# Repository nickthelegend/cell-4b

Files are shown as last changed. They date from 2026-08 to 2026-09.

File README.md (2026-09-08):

# CELL-4B

A blood-gated, airgapped hardware wallet on a Raspberry Pi **4B** — a fork of
[z0r0z/cell](https://github.com/z0r0z/cell) rebuilt around a board you can
actually buy.

The device signs Ethereum transactions, but only after proving that a living
human is present: either a **pulse** at the touch tier, or **fresh blood** in a
cartridge. It never touches the network. Only pixels cross the airgap — a QR
code in, a QR code out.

```
92 × 128 × 42 mm   ·   12 printed parts   ·   6 optical gates   ·   0 network interfaces
```

Upstream's shells are hard-coded to a 65 × 30 mm Pi Zero bay; the Pi Zero 2 W is
unobtainable in India. Everything upstream calls **optics** is preserved exactly.
Everything it calls **derived** — walls, bosses, bays, towers — is rebuilt.

---

## The idea

A hardware wallet proves you have a *key*. This one also proves you are *alive*.

The instrument is a reflectance spectrometer and a laser speckle sensor pointed
at a 3 mm spot. To authorise a signature it has to see something that behaves
like whole blood, across six independent gates:

| gate | measures | passes when |
|---|---|---|
| **G1** return signal | reflectance vs the cartridge's printed white patch | ≤ 0.35 — dark, not an empty well |
| **G2** cellular scatter | NIR / Clear ratio | ≥ 2.2 — cells scatter, solutions don't |
| **G3** haem Soret band | absorption at **415 nm** | ≥ 0.75 — porphyrin, not just red dye |
| **G4** spectral shape | angle against oxygenated whole blood | ≥ 0.995 |
| **G5** free motion | laser speckle decorrelation *D* | ≥ 0.6 — still flowing |
| **G6** motion arrested | *D* after clotting | ≤ 0.25 — it clotted, so it was alive |

G5 and G6 together are the interesting pair: **liquid, then clotting** is very
hard to fake, because it requires the sample to change over time in the way only
real blood does.

The pulse tier is simpler and reusable — a MAX3010x reads bpm, confidence and
perfusion, and refuses anything outside 40–200 bpm or a perfusion ratio outside
0.05–8.0. A perfusion of 10 % is not a heart; it's a finger moving.

## Layout

```
cad/          pure-python CAD kernel -> watertight shells, manifold validator,
              STL/GLB writers, angled-bore mesher. spec.py is the dimensional
              contract; every number tagged [OPTICS] / [HARDWARE] / [DERIVED]
firmware/     what runs on the Pi: gates, spectrometer, pulse, signing, console
firmware/diag/ single-question bench diagnostics (see its own README)
bridge/       browser extension + dApp: captures a transaction, renders a QR,
              never holds a key
viewer/       three.js viewer, vendored, works offline
out/stl/      printable STLs
FINDINGS.md   what broke when upstream's head met real parts
ASSEMBLY.md   step by step
VERIFICATION.md  what has actually been measured, versus claimed
```

## Quick start

**Build the parts:**

```bash
python3 -m venv .venv && .venv/bin/pip install shapely numpy
.venv/bin/python cad/build.py          # audit -> STLs -> plates -> MANIFEST.md
```

`cad/build.py` **refuses to write anything** if `cad/audit.py` reports a failure,
so any plate reaching your slicer has already passed every check.

**Run the instrument:**

```bash
.venv/bin/python firmware/gate_console.py
```

Full-screen live console on the Pi's own display: camera, live colour with the
eight-band spectrum, pulse gate, G1–G6, and the speckle plot with both gate
thresholds shaded.

```
D  chemistry    S  speckle    T  sign with pulse    L  dry/live    W  lights    Q  quit
```

`D` runs the chemistry read in two stages — the white patch at the first stop
(34.6 mm), then **space**, then the sample well at the second (42.1 mm). Both
reads are needed because every chemistry gate is a **ratio**, which is also why
they survive dim emitters: 120 Ω resistors change the illumination constant,
and a ratio divides it out.

## The airgap

The bridge half never holds a key.

```
browser ──► extension ──► QR on screen ──► [ CELL-4B camera ]
                                                   │
                                            gates + signature
                                                   │
[ browser camera ] ◄── QR on the OLED ◄────────────┘
```

The extension announces itself over **EIP-6963** as a walletless provider
holding only an address. It refuses `personal_sign` (4200), refuses to switch
chains (4902), and refuses calldata it cannot read (4100) unless blind signing
is explicitly enabled.

When blind signing *is* enabled, `blindtx.py` renders **"UNREAD CONTRACT CALL"**
plus a hash of the calldata, rather than a friendly summary it cannot justify.
The principle: **refuse to pretend, rather than refuse to sign.** Flip one bit
of calldata and the displayed hash changes.

## How the geometry is checked

Watertight is not the same as buildable, so the audit runs two kinds of check.

**Analytic** — arithmetic on `spec.py`: bore separation at each entry, bore
exits, the six cartridge distances, Pi hole pitch, wall minimums, blind-vent
depth, OLED window inside the PCB, the speckle axis vs the specular lobe in 3-D.

**Sampled** — point-in-solid against real triangles, used where only the
geometry can answer: the cartridge corridor stays open to stop 2, the Pi and its
13.5 mm port stack have somewhere to be, no point is solid in both shells at
once, every part fits the bed.

Bugs the audit caught, each of which would have been a wasted print:

- two screw bosses standing **inside the Pi's footprint**
- a 0.45 mm wall at the part line, from splitting a 2.4 mm wall for a centred
  tongue-and-groove (now a lap joint, 1.0 / 1.25)
- a ceiling built in the wrong Z order, because the finger well is *deeper* than
  the dish it sits in — one prism came out inverted
- the ring collar with `RING_OD` equal to the well diameter, so it was an empty
  solid
- the camera board swinging **below the case floor** at 58°
- the read spot one wall thickness too far in, which silently makes **both
  cartridge stops read the wrong feature**

## What changed from upstream, and why

Upstream's optical head **cannot be assembled as specified**. At a 9 mm sensor
standoff with 5 mm LEDs at 45° / 12 mm, the longest LED body that would clear the
AS7341 board is **0.73 mm**. Full derivation and four other findings in
**[FINDINGS.md](FINDINGS.md)**.

CELL-4B keeps the Ø3 × 6 aperture at the sample end — which is what actually
fixes the 3 mm spot — and moves the sensor to 28 mm on the **flank** at 60°,
behind a wider relief shaft, freeing the vertical axis for the camera.

Untouched: cartridge and well geometry, the white patch, the aperture, 45°/12 mm
LEDs, the 30° laser, the 20 mm lensless camera standoff, travel and both stops.

## Hardware

| | |
|---|---|
| Raspberry Pi 4B | 85 × 56, on 58 × 49 mm bosses, GPIO header facing the optics |
| AS7341 spectrometer | flank boss, 60° off vertical, 28 mm from the read spot |
| 3 × 5 mm LED | 2 white opposed + 1 × 940 nm IR, all at 45° / 12 mm |
| 650 nm laser module | 30° off normal, hardware-interlocked to the cartridge switch |
| OV5647 camera | **lens removed** — a bare die, 45° / 20 mm, 68.8° off the specular lobe |
| MAX3010x | touch tier, pulse and perfusion |
| 1.3" I²C OLED | 4-pin, under the top face with a printed bezel |
| Cartridges | upstream's 51 × 14 × 2.4, unchanged |

Emitters are **sink-driven with 120 Ω and no transistors** — the GPIO sinks the
current, so a lit LED means its pin is *low*. Longer integration buys back what
the resistors cost.

## Notes from the bench

Things that cost real time, recorded so they don't cost it again:

- **The AS7341's channels are a `Reading`, its gain is an enum index.** A `gain`
  of 8 means *index* 8 — 128× — not 8×. `GAIN_STEPS` maps multipliers to indices.
- **A brownout leaves the chip ACKing on I²C with its ADC off**, and every
  channel then reads a hard zero — indistinguishable from a dark chamber, which
  is the reading this device must trust. `Spectrometer.wake()` now forces
  `PON|SP_EN` on construction and raises if it can't.
- **One I²C bus, two libraries, two `busio.I2C` objects.** Their internal locks
  guard nothing against each other, and pulse traffic interleaving into an
  AS7341 SMUX-then-read returns zeros. Everything on the bus takes one lock.
- **The signature fields of an EIP-1559 transaction start at index 9**, not 8 —
  index 8 is `accessList`. Off by one recovers a valid signature for the *wrong
  address*.
- **A QR format string is written MSB-first.** LSB-first produces codes that
  scan 0 of 4 times and look plausible.
- **Sink drive means the short leg goes to the GPIO.** A leg shorting the rail
  will reset the board and can take the pin's output driver with it.

## Credits

- Instrument, physics, and every `[OPTICS]` number:
  [z0r0z/cell](https://github.com/z0r0z/cell) (CC0)
- CAD kernel adapted from
  [nickthelegend/orchestrator-pad](https://github.com/nickthelegend/orchestrator-pad)
  `cad/partlib.py`
- three.js r160, vendored under `viewer/vendor/`

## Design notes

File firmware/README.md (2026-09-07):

# CELL-4B firmware

Bench software for the CELL-4B instrument. Pinout, rails and milestones come
from the enclosure repo's `ASSEMBLY.md` — nothing here re-derives them.

## Install

```bash
./scripts/setup.sh
```

Installs `gpiozero`, `picamera2`, `python3-pil` and `i2c-tools` from **apt**,
enables I²C, then builds a venv with `--system-site-packages` and pip-installs
the three things apt does not carry. The apt-vs-pip split matters: a pip copy of
`picamera2` or `gpiozero` cannot reach the hardware, and the failure looks
exactly like a wiring fault.

## Bring-up, in this order

```bash
.venv/bin/python -m cell4b selftest
```

The checks run in the order that isolates faults fastest, and stop at the
first failure, because each one assumes the ones before it passed.

| # | Check | What a failure means |
|---|---|---|
| 1 | I²C bus | 0x39 absent → SDA/SCL, 3V3, or I²C not enabled |
| 2 | Laser interlock | **fires with slot empty → stop, fix GPIO22 first** |
| 3 | Cartridge switch | no change → not wired; HIGH when seated → inverted |
| 4 | Emitters | no Clear rise → dead FET, wrong resistor, or wrong rail |
| 5 | 415 nm headroom | on the ADC floor → raise ATIME/ASTEP or gain |
| 6 | Light-tight (M4) | Clear ≥ 0.5 % → paint the bores, check baffle and lap |

Checks 2 and 4 are the two that catch a wiring mistake before it looks like
optics. A light leak and a dead LED both read as "415 nm sees nothing".

## Wiring

`ASSEMBLY.md` §5. Repeated here because getting a rail wrong is the one
mistake that destroys a part:

| Pin | Function | Resistor | Rail |
|---|---|---|---|
| GPIO2/3 | I²C1 — AS7341 0x39, MAX30100 0x57, OLED 0x3C | — | 3V3 |
| GPIO12 | white LED #1 | **220 Ω** | **+5 V** |
| GPIO16 | white LED #2 | **220 Ω** | **+5 V** |
| GPIO23 | 940 nm IR | **220 Ω** | **+3V3** |
| GPIO6 | laser ENABLE | — | module off +5 V |
| GPIO22 | cartridge switch | internal pull-up | LOW when seated |

**120 Ω, not the 68/47 the optical design asks for.** Those assume a transistor
in the ground return. `EMITTER_SINK = True`, so the **GPIO carries the current**
and a Pi pin is rated 16 mA — 68 Ω would be 27.9 mA and 47 Ω would be 41.5 mA,
straight past it. Do not "correct" the resistors without also fitting
transistors and setting the flag to `False`.

**The two rails are different rails.** The white LEDs must be on **+5 V**: their
V<sub>f</sub> is ~3.1 V, so from +3V3 they barely conduct. The 940 nm must stay
on **+3V3**: in a sink build the pin floats to (rail − V<sub>f</sub>) while it is
an input, and at V<sub>f</sub> 1.35 V from +5 V that is 3.65 V, over the 3.3 V
pad limit.

Only **one** 2.2 kΩ pull-up pair on the I²C bus — keep the one the breakout
ships with.

## Use

```bash
.venv/bin/python -m cell4b status              # pins, switch, OLED
.venv/bin/python -m cell4b read -n 20          # one averaged reading
.venv/bin/python -m cell4b measure blood-01    # dark / white / sample -> JSON
.venv/bin/python -m cell4b speckle run-01      # M6, 600 s series
```

## Why the integration time is so long

`spectro.py` defaults to ATIME 99 / ASTEP 999 — about 278 ms. The sensor sits
at **28 mm** from the sample, not upstream's 9 mm, so it receives roughly
(28/9)² ≈ 9.7× less light. Short integrations put 415 nm on the ADC floor.

415 nm is the channel the instrument exists to read: it is where haemoglobin
absorbs and red food dye does not. If it will not lift off the floor on a white
card, **say so in the writeup** — per `ASSEMBLY.md` §6 that is a result, not a
defect to bury.

## What this deliberately does not do

There is no threshold anywhere in this code and no verdict. `measure.py`
returns reflectance and writes JSON; it does not tell you what the numbers
mean. Upstream `BUILD.md` §15 M7 is where `thresholds.json` gets earned — from
data, with an ROC. A number hard-coded now would be inventing the answer.

Read upstream `SAFETY.md` before any of this involves blood. One device, one
person, one lancet per use, sharps container.

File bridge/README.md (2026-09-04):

# CELL bridge

A browser extension that routes a dApp's **value transfers** to a CELL device,
so a transaction any website builds can be authorised with blood.

    dApp ──eth_sendTransaction──► shim ──fields as QR──► CELL ──raw tx──► chain

## What it does and does not do

It intercepts `eth_sendTransaction` and nothing else. Account lists, chain
switches and reads pass straight through to whatever wallet is installed,
because CELL is a **signer, not a wallet** — it has no accounts to enumerate.

**It refuses calldata**, and that is not a limitation to work around. From
`firmware/eth.py`:

> NO CALLDATA. `data` must be empty. Arbitrary EVM calldata cannot be rendered
> as a sentence the owner can evaluate.

So a swap, an approve or a mint is passed back to your normal wallet with an
explanation. A plain transfer goes to the device. On **wei.domains**, "send
eth" is a plain transfer, which is why it works there.

**It sends fields, never a digest.** The device rebuilds the transaction from
those fields and hashes what *it* built. A page that lies about the recipient
gets rendered truthfully on the device's own screen. That property is the whole
point of the device, and it only survives if this extension never takes the
shortcut of hashing anything itself.

## Try it without hardware

    .venv/bin/python cell4b/bridge/mock_cell.py

The mock is not a simulation of the optics. It is the part of the device the
browser can see: it renders the transaction with `ops.EthereumSpend` — the same
code the OLED uses — pretends a gate ran, and signs with upstream's real
`eth.py`. **The bytes it returns are valid; only the liveness is fake.** Its key
is the all-ones test scalar, printed in the file. Testnet only.

    --gate blood|touch|refuse     what the pretend gate decides
    --delay N                     how long it pretends to take

Load `cell4b/bridge/extension/` at `chrome://extensions` → Developer mode →
Load unpacked. Then open a dApp and send.

## Wire format

`CELL-EVM-1`. Upstream's `qr.py` frames PSBTs, which are Bitcoin; there is no
EVM equivalent in the repo, so `wire.py` defines one and reuses the same
`pNofM base64` framing a webcam already knows how to collect.

`wire.py` and `extension/lib/wire.js` must agree byte for byte — the digest the
two screens compare is a SHA-256 over canonical JSON, so a stray space in
either makes every transfer look tampered with. `e2e.test.html` asserts they
match.

## Tests

| file | asserts |
|---|---|
| `qr.test.html` | every frame size round-trips through the browser's own `BarcodeDetector` |
| `harness.test.html` | the harness itself, against a segno-generated matrix |
| `e2e.test.html` | fields → QR → device → signed tx, digests agree, calldata refused |

Serve the directory and open them; they need a real browser for
`BarcodeDetector`.

## Vendored

`lib/qr.js` and `lib/keccak.js` are written out rather than imported: an MV3
extension cannot pull script from a CDN. Both are tested against known vectors
— keccak against the three standard digests and the EIP-55 examples, QR against
`BarcodeDetector`.

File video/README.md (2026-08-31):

# CELL-4B demo video

```bash
python3 -m http.server 8731                 # serve the viewer
../.venv/bin/python     video/record.py     # 12 scenes -> video/out/raw/*.webm
../.venv-tts/bin/python video/tts.py        # 12 Kokoro lines -> video/out/vo/*.wav
../.venv/bin/python     video/assemble.py   # -> video/out/cell4b-demo.mp4
```

`recording.md` is the scene map. `scenes.py` holds each scene's narration line
and the actions that drive the viewer.

## How it records

Playwright drives a **headless Chromium** and captures with the browser
context's own `recordVideo`. Only the browser viewport is written to a file —
the desktop is never touched and the machine stays usable while it runs. Every
click, dropdown change and orbit is a real interaction against the real
`out/manifest.json` and the real GLBs.

**One browser context per scene, so one video file per scene.** Any single
scene can be re-recorded without disturbing the others:

```bash
../.venv/bin/python video/record.py --only 05_cutaway
```

Two guards keep the footage honest:

- the recorder **fails the run** if any console error appears while recording,
  so nothing ships with errors in frame;
- nothing is staged — the audit badge shows whatever the manifest says. When
  the on-screen pair count changed from 52 to 60, the narration was rewritten
  to match rather than the other way round.

## Pacing

Each scene is cut to its **measured** narration length — read back off the
generated WAV with ffprobe, never estimated. Footage that runs long is
speed-ramped; footage that runs short holds its last frame. No scene is ever
cut short of its line.

## Changing runtime without cutting content

`scenes.json` carries a speed multiplier per scene.

```bash
python3 video/rerender.py                 # apply whatever is in scenes.json
python3 video/rerender.py --target 75     # pick multipliers to hit 75 s
```

Video is retimed with `setpts`, audio with `atempo`, so pitch stays natural.
Scene mp4s are cached and keyed on their multiplier — changing one scene
re-encodes only that scene. Nothing is re-recorded and no content is dropped.

## Subtitles

One narration line = one cue. The caption is rendered **in the page** rather
than burned by ffmpeg: this ffmpeg build has no `drawtext` or `subtitles`
filter, and the browser gives proper text shaping for free. Because the cue is
in the footage and static, retiming can never desync it.

## Two virtualenvs

Kokoro needs spacy, which has no wheels for Python 3.14, so TTS lives in its
own 3.10 environment:

```bash
python3.10 -m venv .venv-tts && .venv-tts/bin/pip install kokoro soundfile
```

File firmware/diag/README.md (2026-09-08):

# Bench diagnostics

Single-purpose scripts for one question each, written while bringing the
optical head up. They exist because the failures on this instrument look
alike from the outside: a blocked aperture, a dead emitter, a disabled ADC
and an empty chamber all read as **zero**, and zero is the value the blood
gate has to trust absolutely.

Each script is built to separate one of those from the others.

| | asks |
|---|---|
| `as7341probe.py` | is the chip alive? Dumps ID, ENABLE, ATIME/ASTEP, gain, and polls STATUS2 for AVALID |
| `aperture.py` | is it blind, or is the chamber dark? Its own LED at ~0 mm against the room |
| `ledspot.py` | does an emitter light, and where? Per-pixel difference with the global level removed, so room light cannot fake it |
| `borecheck.py` | is there an optical path between the sensor and the chamber at all? |
| `torchhunt.py` | can *any* external light reach the die, at 100 ms for live hunting |
| `aim.py` | live readout at the console's gain, for seating an emitter and watching the return climb |

## The one that matters

`aim.py` runs at **gain 256**, deliberately. At gain 8 a real return through
the Ø3 aperture reads 1–2 counts and is indistinguishable from noise — which
is exactly how an earlier version of this script hid a working optical path
and cost an afternoon of chasing the wrong fault.

```bash
.venv/bin/python diag/aim.py 180
```

Both whites come on and it prints a bar at ~5 reads/s with a running best.
Move **one** emitter at a time. Put something reflective at the read spot
first — an empty chamber returns nothing however well aligned it is.

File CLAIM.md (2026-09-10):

# Claim — poidh bounty 24

**CELL-4B**, a Raspberry Pi 4B build of [z0r0z/cell](https://github.com/z0r0z/cell).
Everything below is verifiable by anyone with an RPC endpoint.

## Device

| | |
|---|---|
| address | `0xD9B4b074e48cfF75538E6468748C0FA2C16De5F5` |
| seed | generated on the device, never left it |
| network | Ethereum **mainnet** |

The key had **never signed anything** before this build: the transactions
below are nonces 0 through 3 on a fresh account.

## On chain

Four mainnet transactions, all `SUCCESS`, all from the device key.

| what | nonce | block | tx |
|---|---|---|---|
| `pulse.wei` commit | 0 | 25934252 | [`0x86b3273c…`](https://etherscan.io/tx/0x86b3273c65ad551aef0cfd211b4880e1e9ec2ec62cd23c575286083242f3efb7) |
| `pulse.wei` register | 1 | 25934352 | [`0xf6835b12…`](https://etherscan.io/tx/0xf6835b1204cba15e2aae91b4c2c26390bf0a6940d12ac4542804a01d0ba350ea) |
| `blood.wei` commit | 2 | — | — |
| `blood.wei` register | 3 | 25942667 | [`0xec1fa23b…`](https://etherscan.io/tx/0xec1fa23b839fa46d38bdd20180d2e79a32802ef148b20962eb9c5af5487e6504) |

**Two `.wei` domains registered and owned by the device key.** WNS uses
commit-reveal, so each name took two transactions and a wait between them.

## Against the four requirements

**1. The assembled device, running.** Video. Full-screen console on the Pi's
own display: both cameras, the live pulse gate, the eight-band spectrometer,
G1–G6, and the speckle plot with both thresholds drawn.

**2. A signature authorised by a pulse.** The gate reads bpm, confidence and
perfusion from a MAX3010x and refuses on any of the three. A passing read:

```
OK bpm 80.0    OK conf 0.820    OK perfusion 3.609    (want 0.05-8.0)
PULSE PRESENT -- a living finger
```

It refuses far more often than it passes — a moving finger reads perfusion
around 10 %, well outside the window, and is rejected:

```
perfusion 9.43% -- far too large for blood volume; this is the finger moving
```

**3. A transaction on chain.** Four of them, above.

**4. A signature authorised by fresh blood.** **Not claimed.** The chemistry
gates could not be run to a standard worth claiming on a real sample. See below.

The signing pipeline itself has been run end to end — gates, then signature,
then broadcast — using the console's simulated-sample mode, which the console
labels on screen: *"G1–G6 above were computed from modelled photons, not from
a sample. The transaction and the signature are real."* That demonstrates the
integration. It is not evidence that blood authorised a signature, and it is
not presented as such.

## The airgap

The browser extension holds **no key** — only an address, announced over
EIP-6963 as `life.proof.cell`. It builds an EIP-1559 transaction, frames it,
and shows a QR. The device rebuilds it **from the fields**, renders it on its
own screen, gates, signs, and shows the signature back as a QR.

Contract calls are blind-signed and say so. The device does not invent a
summary it cannot justify:

```
!! UNREAD CONTRACT CALL !!
  the device cannot explain this
  to       0x0000000000696760E15f265e828DB644A0c242EB
  value    0 ETH
  selector 0xf14fcbc8
  data     36 bytes
  hash     <sha256 of the calldata>
```

Flip one bit of calldata and the displayed hash changes.

## What did not work, and the numbers

`BOUNTY.md`: *"A failure is a claim too. If dye passes a gate, or real blood
fails on your optics, post it."* Both happened. `FINDINGS.md` 10–16.

**A red dye passes G2 and G3 when the white reference collapses** (16).
Measured, red dye, this device:

```
dark 5312   white patch 5140   sample 5280      <- reference darker than dark
G2 -> 1e15    PASS
G3 -> 1.0000  PASS
```

`chemistry_gates()` forms its ratios without checking the reference returned
any light. Once `white - dark <= 0`, G2 divides by ~zero and G3's index goes
to 1.0 as R415 goes to zero — a dead 415 channel is arithmetically identical
to perfect Soret absorption. G3's docstring anticipates it and does not act:
*"Gate 1 has already established that the sample returns real signal."* It
never checks whether G1 ran. **Fixed here** by refusing before the gates run.

**The white LEDs cannot excite the Soret band** (12). 415 nm reads exactly 0
at gain 128, 256 **and** 512 while 445 doubles each time. Blue-pump phosphor
emitters start around 445. G3 cannot pass for any sample on the BOM parts.
Fixed by fitting a **400 nm violet emitter**, which gives a clean 415 channel
at 6.5× selectivity with no housing fluorescence — after which G3 scored a red
dye at **0.2233** against its 0.75 bar, on a real two-position read.

**Real blood failed G5 on these optics** (14). A clotting series ran
`D 0.94 → 0.22` — endpoints that satisfy G6's `d_late ≤ 0.25` and
`drop ≥ 0.35`. G5 refuses first on speckle contrast: `K = 0.073` against a
0.10 floor, **flat across a 66× exposure sweep**. Grain size, not exposure.

**A 940 nm emitter cannot be sink-driven from +5V by a 3.3V GPIO** (10, 15).
`5.0 - 3.3 = 1.7 V` exceeds its 1.3 V forward voltage, so it has **no off
state**, and a released pin drives 5V through the pin's ESD clamp into the
3.3V rail. It cost GPIO12, and the emitter then ran lit for hours beside the
AS7341. The sensor's dark floor has been between 826 and 5300 counts since,
against a signal of ~200 — which is why the chemistry gates cannot be trusted.

## Honest status

**Working:** device assembled and running; pulse gate; airgapped bridge; blind
signing with a calldata hash; four mainnet transactions; both white emitters;
940 nm on the correct rail; 400 nm violet with a clean 415 nm channel;
two-position reads.

**Not working:** chemistry gates, on a dark floor that swamps the signal;
G5/G6, on speckle contrast below the sanity floor.

**Not claimed:** a signature authorised by fresh blood.

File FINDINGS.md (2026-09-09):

# Findings against upstream CELL

Everything here came out of trying to *build* `z0r0z/cell`'s optical head
around real parts. Each one is reproducible from this repo — `cad/audit.py`
re-derives them on every run, and the arithmetic is in `cad/spec.py`.

`BOUNTY.md` asks claimants to "say what you had to change to make it work, if
anything". This is that list.

---

## 1. The 9 mm sensor standoff cannot be built with 5 mm LEDs at 45° / 12 mm

**Severity: blocking. The optical head as specified does not assemble.**

`BUILD.md` §9 fixes three numbers at once:

| | |
|---|---|
| AS7341 face above the sample | **9.0 mm** |
| White LEDs | **45°**, **12 mm** from the spot centre |
| LED part | 5 mm through-hole (`BOM.csv`) |

Take the LED axis through the read spot at 45°. Its **tip** sits at
`r = 12·sin45 = 8.49`, `z = 12·cos45 = 8.49`. A 5 mm through-hole LED is about
**8.6 mm** long behind the dome, so the body runs on to slant 20.6, i.e.
`r = 14.57`, `z = 14.57`.

The AS7341 breakout is a **30.5 × 23 mm** board that has to sit centred on the
aperture at z = 9.00…10.60. The LED axis crosses that slab at **r = 9.00…10.60**
— and the *narrowest* half-width of a 30.5 × 23 board is **11.5 mm**. So the LED
body passes through the board's footprint **at every azimuth**. There is no
rotation of the board that avoids it.

Solving for the longest LED body that would clear a board at 9 mm:

```
L_max = 9.0 / cos(45°) − 12.0 = 0.73 mm
```

**0.73 mm.** No through-hole LED exists at that length.

Reproduce:

```bash
python3 cad/audit.py | grep -A2 sensor-standoff
```

### What CELL-4B does instead

Keeps the **Ø3 × 6 aperture tube at the sample end unchanged** and raises the
sensor to **28 mm**, with a Ø5 relief shaft above the tube so the tube is still
the narrowest element in the path.

This matters because the tube — not the sensor distance — is what fixes the
3 mm spot inside the Ø4 well, which is the property §9 actually argues for
("the sensor never sees the meniscus"). What is lost is collected flux, down by
`(28/9)² ≈ 9.7×`, and that is recoverable twice over:

- `ATIME`/`ASTEP` are software. §7 already spends 281 ms on a chemistry read
  that happens once per cartridge.
- Every gate normalises against the printed white patch, which divides the
  illumination-and-collection constant out entirely. Gate 2 is explicitly a
  *white-normalised* NIR/Clear ratio; Gate 3 is a normalised difference index;
  Gate 4 is a spectral **angle**. None of them has an absolute-radiance term.

**Open question for a panel run:** whether 9.7× less flux pushes the 415 nm
channel far enough down that the Gate 3 index gets noisy. 415 nm is already
expected to sit near the ADC floor for whole blood (§7: "roughly 4,600
absorbance units per centimetre"), which is exactly why Gate 3 is a bounded
index rather than an absorbance. This is the first thing to measure.

---

## 2. The AS7341 breakout does not break out the LDR / LED driver pin

**Severity: the buying guide names a part that does not exist as described.**

`BUILD.md` §6, "Buying it":

> **AS7341** — Adafruit 4698, or a clone that brings out the **LDR/LED driver
> pin**. […] Boards that omit that pin cannot drive LED #1 directly and §9's
> wiring does not apply.

Checked against both candidate boards:

| Board | Pins actually broken out | LDR? |
|---|---|---|
| Adafruit 4698 | VIN, GND, SCL, SDA, **INT**, **GPIO** | no |
| Waveshare AS7341 | VCC, GND, SDA, SCL, **INT**, **GPIO** | no |

Sources: Adafruit's own pinout page for 4698, and the Waveshare AS7341 wiki
pinout table. Neither exposes LDR; both expose INT and GPIO instead. Adafruit
4698 is also out of stock at Adafruit and at Robu.

**Workaround, and it is cheap:** drive white LED #1 from its own GPIO through a
2N7000, exactly like LED #2. Cost is one MOSFET and one GPIO; what you lose is
the AS7341's synchronised flash/measure timing, which you then sequence in
firmware. `diagrams/wiring.svg` should be regenerated — it currently annotates
the AS7341 with "Drives white LED #1 on its LDR pin."

Note also that the Waveshare board carries **two onboard white LEDs**. They are
unusable here: they sit on the PCB beside the sensor, i.e. at near-normal
incidence, which is the geometry §9 exists to avoid ("a normal-incidence lamp
would swamp the sensor with surface reflection carrying zero chemical
information").

---

## 3. "Co-siting" the IR LED with white LED #1 is not physically possible

`BUILD.md` §9 and `BOM.csv` both say the 940 nm LED is "co-sited with LED #1".

At `LED_SLANT = 12` and `LED_BORE = 5.4`, two bores at the same slant and the
same azimuth **are the same hole**. Any real separation has to be angular. The
required separation, for a printable 1.0 mm wall between two Ø5.4 bores whose
45° sections are 7.64 mm across, is **≥ 57.4°** at the 9 mm entry radius.

CELL-4B puts the whites opposed at 0° / 180° (which §9 does require — "two
opposed LEDs cancel directional shading from droplet asymmetry") and the IR at
**90°**. All three still illuminate at 45° / 12 mm and all three are normalised
against the same printed white patch, so Gate 2's white-normalised NIR/Clear
ratio is unchanged.

---

## 4. The camera and the AS7341 both want the vertical axis

§9 draws the chemistry path with the AS7341 "0°" above the spot, and draws the
speckle path with the camera vertical at "~20 mm from the spot". Both diagrams
put their sensor on the same axis. They cannot both have it.

CELL-4B tilts the speckle path to **45°** and places it at azimuth 225°. The
angle is pinned between two hard limits:

- **≥ 42.9°**, or the bore leaves through the head's top face and lands under
  the AS7341 board;
- **≤ ~48°**, or the 25 × 24 mm camera PCB — which hangs perpendicular to the
  axis only 20 mm from the spot — swings down through the case floor. At the
  58° I first tried, its lowest corner reached **Z = 1.3 mm**, below a 2.4 mm
  floor.

45° satisfies the property §9 actually asks for: it is **68.8° off the laser's
specular lobe in 3-D**, checked in `audit.check_optics()` as a direction
comparison rather than an azimuth difference (azimuth alone flatters any design
where the two tilts differ).

---

## 5. Ø8 is too big for the speckle bore

At a 58° tilt a Ø8 bore has a **15.1 mm** elliptical cross-section, which
crowds every other bore out of a Ø52 head. Reduced to Ø6, which still
over-fills an OV5647 die (3.6 × 2.7 mm) by a wide margin.

---

## 6. TRAVEL and the two stops have to share one datum

Not an upstream error — an ambiguity that is easy to get wrong, and I did get
it wrong first.

§8 gives `travel 31.6` as "front face to read spot", and gives the stops as
insertion depths (34.6 and 42.1). Those only agree if **both** are measured
from the **outer** front face:

```
STOP2 − WELL_FROM_TIP = 42.1 − 10.5 = 31.6 = TRAVEL   ✓
STOP1 − PATCH_FROM_TIP = 34.6 −  3.0 = 31.6 = TRAVEL  ✓
```

Measuring TRAVEL from the inner wall face instead puts the read spot one wall
thickness too far in, and **both stops then read the wrong feature** — the
patch reads partly moat, the well reads partly body. Nothing about the part
looks wrong. `audit.check_cartridge()` pins both identities.

---

## 7. A Ø52 head leaves no room for the cartridge switch

**Severity: functional. The laser interlock had nothing to interlock.**

The cartridge is only exposed *inside* the case in one strip: between the inner
front wall and the optical head.

```
TRAVEL - head radius - wall  =  31.6 - 26 - 2.4  =  3.2 mm
```

3.2 mm. Everywhere else along its travel the head is directly over it. So the
cartridge-present microswitch — which upstream also makes the **hardware laser
interlock**, wired in series with the laser's supply — had nowhere to sit where
the cartridge could ever press it.

This is worth stating plainly because it is a *functional* failure, not a fit
failure: the switch sat in the case with 1.9 mm of clearance on every side and
315 geometry checks were perfectly happy. It simply was never going to be
touched. `audit.check_function()` now asserts the lever actually overlaps the
channel, at cartridge height, over the cartridge's travel.

**Fix:** the head shrinks to **Ø44**. Every bore exit stays valid — the LEDs and
the speckle path still leave through the side wall at z = 27.4, and the laser
still leaves through the top at r = 16.2 with 2.1 mm of wall — and the front
strip opens to **7.2 mm**, which takes a subminiature switch body with its
lever in the channel.

Two knock-on fixes fell out of it: the head's mounting posts moved to r = 15 at
30° off the X axis, and the slot baffle gained a notch for the switch body,
which then fills the notch and keeps it light-tight. **The post move was
wrong** — §9 is what it cost and how it was found.

## 8. Upstream's touch tier has no drawn optical path — and the fix is a flip

`BUILD.md` §4 says photoplethysmography happens "through the same ring bore the
cartridge sits under", and `hardware.py`'s `RealTouchSensor` says it "shares the
spectrometer head", driving the same white and IR LEDs. Upstream's CAD backs the
first half of that up exactly:

```
DISH_X = 28.5     ring / dish centre
SLOT_X = 28.5     cartridge slot centre      ONE AXIS
```

and it cuts the port as a **through-hole** — `s.hole(circ(PORT_D, …), top −
DISH_DEPTH − CEIL − 1.0, top + 1.0)` — so a finger above and a cartridge below
genuinely share one optical path.

What is never drawn is how the sensor sees both. `build-sheet.svg` labels the
head **"AS7341 / aperture Ø3.0 × 6.0 / 0° observe"** sitting above the
cartridge, facing **down**:

| | |
|---|---|
| cartridge well | **15.80** — below the sensor ✅ |
| finger on the glass | **25.72** — **above** it ❌ |

A single AS7341 aperture cannot look both ways, and the three blood LEDs are
aimed 45° **downward** at a spot 9 mm below the sensor, so neither the emitters
nor the detector face the finger. The touch tier is specified in prose and in
firmware, and has no geometry.

### What CELL-4B does: the flip-mount

One board, one pad, two orientations:

```
chip DOWN  at Z=35.8  ->  down the relief shaft, reads the cartridge
chip UP    at Z=37.4  ->  up the ring port, reads a fingertip
```

`sensor_carrier` is deliberately **symmetric** about its own mid-plane — same
four M2 holes, same central window — so it clamps the board either way up
without a second part. That symmetry is the whole trick: without it the touch
tier needs a second AS7341, which is another ~₹2,000 for a board you already
own.

`touch_collar` carries the white and IR LEDs at the **same 45° / 12 mm** the
blood tier uses, aimed **up** at the finger. It is Ø24 rather than the head's
Ø44 for a concrete reason: a 45° bore aimed at a spot above only leaves through
the **side** wall if the wall is nearer than the standoff. At Ø44 the bores
would exit the collar's underside and the LEDs could never be inserted.

The port is now a real through-hole with a Ø10.4 × 0.6 rebate at the ceiling's
inner face, so the Ø10 window drops in from below and seals the chamber —
exactly as upstream cuts it.

### And it hits the same wall as §1

This is the part worth noticing. The touch side runs into **precisely the
constraint that breaks upstream's blood side**: 5 mm LEDs at 45° / 12 mm have
to clear a 30.5 × 23 board.

```
standoff  9 mm -> LED body ends  -5.57 mm  THROUGH the board
standoff 14 mm -> LED body ends  -0.57 mm  THROUGH the board
standoff 16 mm -> LED body ends  +1.43 mm  clears
standoff 19 mm -> LED body ends  +4.43 mm  clears, and clears the carrier too
```

Same geometry, same failure, same resolution — a longer standoff. That the
constraint reappears independently on the other tier is decent evidence §1 is a
real property of the specified optics and not an artefact of how I built it.

**Cost:** the case grows to 59.8 mm tall, because the finger has to sit 19 mm
above a sensor that is itself 35.8 mm up.

## 9. My own r = 15 head posts were unbuildable — and 4 of them are impossible

This one is mine, not upstream's. §7 moved the head's mounting posts to r = 15
at azimuths 30/150/210/330 and the audit passed 346 checks. It was wrong in
three separate ways at once, and every check was blind to all three.

### What was actually wrong

| | |
|---|---|
| Posts az 30 and az 330 | **inside the camera pocket** — distance 0.00 mm. The tap hole opened straight into the camera cavity. |
| All four posts | **0.08 mm of wall** to an LED/IR bore at z ≈ 19.95, where `MIN_WALL` is 1.0. |
| Deck: AS7341 M2 × 4 vs post M2.5 × 4 | centres **1.52 mm** apart, radii summing to 2.55 — the holes **merged** into figure-8 slots. |
| Deck: all four M2.5 heads | sat **under the AS7341 board**, so it could not lie flat. |

The azimuths were the root: 30/150/210/330 is exactly 15° off the bore
azimuths 45/135/225, and 15° at r = 15 is 3.9 mm of arc. The AS7341's own hole
pattern lands at atan2(9, 12.75) = 35.2°, so the two four-hole patterns were
placed on the same diagonals by two different pieces of reasoning.

### Why nothing caught it

* `check_bore_separation()` compares **bores to bores**, never a fastener to a bore.
* `check_head_posts()` tested only the cartridge corridor and the head radius.
* `unary_union` merges overlapping cuts **silently**. The mesh stayed
  watertight and manifold, so `validate()` was satisfied.
* Screws are not modelled, so nothing knew a screw head lands on the deck face
  the board sits on.

This is the same lesson as `check_function()`: **fitting is not working**, and
a check that only asks "does it fit" cannot see a screw that has nowhere to go.

### Four interior posts are impossible, not merely awkward

Searching the head's whole interior on a 0.1 mm grid against the real bore
sections and pockets: the **+x/+y quadrant contains zero feasible cells** at
any radius and azimuth. The camera pocket (x 5.4…28.7, y ±12.8) and the 45°
LED bore between them own that sector. With raised screw heads there is no
feasible position **anywhere**, because the head must also clear the board.

So the fastening left the optical volume. Outside the head there are 31,822
feasible cells with 16–23 mm of clearance, versus 0.08 mm inside it.

### The fix: three lugs, outside

| Lug | Azimuth | Clearance | Note |
|---|---|---|---|
| 1 | 115° | 2.5 mm | the CSI ribbon owns +Y, so not 90° |
| 2 | 180° | 12.8 mm | |
| 3 | 305° | 5.9 mm | needs the switch on −X |

r = 28, Ø9 pads. One M2.5 per lug runs deck ear → head lug → shell boss. Three
because those are the only zones that exist — and three is correct anyway: it
cannot rock, and the read spot sits inside the triangle. The screws are now
14 mm clear of the AS7341's board, so its four M2 holes are plain, separate,
reachable holes.

Two knock-ons of my own: the **microswitch moved to −X** (the channel is
symmetric, so it is a sign flip), and the **slot baffle gained a second notch**
for the 305° boss — the same treatment the switch notch already had.

### What now guards it

| Check | Catches |
|---|---|
| `check_head_lugs()` | a fastener inside a bore, a pocket, or an **insertion corridor** — the swept path a part travels down, not just where it ends up |
| `check_fasteners()` | two holes in one part merging; a screw head under a part stacked above it |
| `check_slot_light()` | **measures** the daylight past the baffle instead of asserting the offset is positive |
| `check_docs()` | lug count, every lug azimuth, the switch side, the head diameter |

Run against the old geometry these produce **20 failures**. Against the current
geometry, none. A check that cannot fail is not a check, so that asymmetry is
the point.

### The residual, stated plainly

`check_slot_light()` measures **0.80 mm** of daylight past the baffle, in two
gaps of one printed fit each: one beside the switch body, one beside the 305°
boss. Both are filled by the part that sits in them, but neither is sealed.
The chamber's real seal is the head skirt, checked separately. The budget is a
regression bound, not a target.

## 10. A 940 nm emitter cannot be sink-driven from +5V by a 3.3V GPIO

**Severity: blocking, and it damages the pin.**

Sink drive puts the GPIO on the cathode. The LED is therefore off only when
the pin is driven to the rail voltage the anode sits at — and a 3.3V pin
cannot reach +5V. What is left across the LED is the rail difference:

```
5.0 V (rail) − 3.3 V (pin driven high) = 1.7 V
```

A white LED has Vf ≈ 3.0 V, so 1.7 V cannot light it and sink drive from +5V
is fine. A **940 nm** LED has **Vf ≈ 1.3 V**. 1.7 V is comfortably over it, so
the IR emitter has **no off state at all**. Measured, holding the pin high:

| pin state | AS7341 NIR |
|---|---|
| released (input) | 33 701 |
| driven HIGH — nominally OFF | 27 939 |
| driven LOW — ON | 34 506 |

Released and ON are the same reading. Worse, a released pin is an *input*, so
+5V drives current through the LED into the pin's ESD clamp diode and out into
the 3.3V rail. That is out-of-spec for the pad and back-feeds a rail from a
diode never intended to carry it.

This build lost **GPIO12** to what was almost certainly the same mechanism a
day earlier: the pin stopped driving, `pinprobe` read it shorted to ground,
and white #1 had to be moved to GPIO13.

**The fix is one wire: the IR anode belongs on +3.3V.** Then a pin driven high
puts 0 V across the LED, and a released pin cannot forward-bias anything.

`hw.py`'s module docstring **already said this**, with the arithmetic:

> the 940 nm on +3V3, because a sink LED floats its pin to (rail − Vf) while
> the pin is an input, and 5 − 1.35 = 3.65 V is over the pad limit.

It was rediscovered from measurements over about an hour. The header of
`hw.py` is a wiring specification, not commentary.

---

## 11. EMITTER_OHMS is a calibration constant, and it disagreed with the build

**Severity: silent 1.8× measurement error.**

`spectro.atime_for()` scales integration time from the emitter resistor
specifically to hold collected light constant as that resistor changes:

```
ATIME = round((99 + 1) · ohms / 120) − 1      →  120 Ω: 99    220 Ω: 182
```

`spectro.EMITTER_OHMS` said **220**. `hw.py`'s header said **120 ohm on all
three emitters**. Both cannot be true, and the constant *is* the calibration.

Every bench script written during bring-up copied `atime=99` out of the
console. On 220 Ω hardware that under-integrates by **1.8×** — and it does not
present as a wrong constant, it presents as a **dim instrument**. Hours were
spent looking for a missing optical path that was partly just a missing
factor of 1.8.

The diagnostics now derive it (`atime_for(EMITTER_OHMS)`) rather than
hardcoding either value, so changing the resistor changes one constant.

---

## 12. The white emitters cannot excite the Soret band. G3 cannot pass.

**Severity: blocking for blood chemistry. Needs a part that is not in the BOM.**

G3 is the haem gate, and it is the only one specific to a **porphyrin** rather
than to "red and cell-like". It reads the Soret absorption at **415 nm**:

```
soret_index = (R630 − R415) / (R630 + R415)     must be ≥ 0.75
```

The white emitters are blue-pump phosphor LEDs. Their emission begins around
445 nm; at 415 there is essentially nothing to reflect. Measured with both
whites lit, 916 ms integration, three gains:

| gain | 415 nm | 445 nm | 630 nm |
|---|---|---|---|
| 128× | **0** | 19 | 17 |
| 256× | **0** | 39 | 33 |
| 512× | **0** | 71 | 63 |

Every doubling of gain doubles 445 and 630. **415 stays at exactly zero.** This
is not a weak signal that more integration recovers — there is no signal.

**G3 cannot pass, for any sample, on these emitters.** A ~405–415 nm violet LED
is required. It is the highest-value missing part on the instrument: without
it the device has no gate that distinguishes haem from any other red thing.

---

## 13. Demonstrated: a red marker is indistinguishable from blood, as built

**Severity: this is the attack the device exists to reject.**

Run blind, by the builder, without telling the operator what was in the well:
the cartridge well was coloured with a **red marker pen** and presented as
possibly blood.

The instrument could not tell, and neither could the person reading it. The
correct call ("not blood") was reached, but for a weak reason — the spectrum
was not strongly red *either*, because the noise floor was 26× the signal, so
everything reads washed out and neutral.

| | net counts above dark |
|---|---|
| 415 | 5 |
| 445 | 47 |
| 480 | 33 |
| 515 | 37 |
| 555 | 51 |
| 590 | 67 |
| 630 | 58 |
| 680 | 21 |

Reproducible across two runs to within ~5 counts per band, so the shape is
real — but a red marker on a white well should give 630/680 clearly dominant
with blue crushed, and this gives 555 ≈ 630.

The finding is not "the spectrometer is noisy". It is that **the specific gate
designed to defeat this specific attack was the one that could not run.** G3
exists because, in `blood_gate.py`'s own words, *"no common red substance —
food dye, ketchup, beet juice, theatrical blood — has one."* With 415 nm dark,
a dye and real blood produce the same verdict.

A red-dye rejection claim is only as good as the 415 nm channel behind it, and
that channel must be shown to have signal before the claim means anything.

---

## 14. Speckle contrast is below G5's sanity floor, and exposure does not fix it

**Severity: blocking for G5/G6.**

G5 checks that it is looking at speckle at all before it looks at motion:

```python
kbar = mean(K over the early window)
if kbar < th.speckle_contrast_min:      # 0.10
    return "No speckle — laser off, or nothing coherently scattering."
```

Measured with the laser on a static target, sweeping exposure over 66×:

| exposure | K | | exposure | K |
|---|---|---|---|---|
| 500 µs | 0.0733 | | 8 000 µs | 0.0664 |
| 1 000 µs | 0.0583 | | 16 000 µs | 0.0686 |
| 2 000 µs | 0.0558 | | 33 000 µs | 0.0677 |
| 4 000 µs | 0.0617 | | | |

**Flat.** If temporal averaging were washing the speckle out, short exposures
would win clearly; they do not. The grains are smaller than the sensor's
pixels, which is geometry — grain size scales as roughly `λ·z / spot`, so it
is set by the illuminated spot size and the 20 mm camera standoff, not by any
camera setting.

A clotting series measured on real blood ran `D 0.94 → 0.22` — endpoints that
satisfy G6's `d_late ≤ 0.25` and `drop ≥ 0.35` — but **G5 would have refused it
first on K**, and G6 also requires `rho ≤ −0.70`, a steady decline, which an
oscillating series does not provide. Endpoints that look right are not the
same as a gate passing.

---

## 15. Finding 10 has a second casualty: the sensor beside the emitter

**Severity: blocks all chemistry. Cause not established -- see the
correction at the end of this section.**

Finding 10 records that a 940 nm emitter sink-driven from +5V has no off
state, because the rail difference (5.0 - 3.3 = 1.7 V) exceeds its 1.3 V
forward voltage. That was written up as a threat to the GPIO, and GPIO12 was
lost to it.

The GPIO was the cheap casualty. The emitter sits millimetres from the
AS7341 in the same head, and it ran **continuously for hours** -- not
because anything switched it on, but because nothing in software could
switch it off.

Measured afterwards, dark floor at gain 256 / 916 ms, chamber sealed, every
emitter pin actively held off:

| | clear | nir |
|---|---|---|
| before, at night | **0** | **0** |
| after | **~6000** | **~38 000** |

38 000 of 65 535 is **58% of full scale consumed by dark current** before any
light arrives, worst on NIR -- the band an IR emitter would heat hardest.

Two tests separate damage from temperature, and it fails both:

* **Cold start.** Powered down, cooled, restarted: the floor was already
  5045 at 112 s uptime and 44.8 C. Thermal dark current starts low and
  climbs; this starts high.
* **Direct cooling.** Ice against the sensor die: SoC 45.7 -> 41.8 C, floor
  6263 -> 5965. **A 5% drop.** Dark current halves roughly every 8 C, so a
  4 C fall should have taken ~30%. It is not temperature-driven any more.

The instrument is otherwise working. Both whites light, the 400 nm violet
gives a clean 415 nm channel with 6.5x selectivity and no housing
fluorescence, the two-position read resolves the patch from the well, and
G3 scored a red dye at 0.2233 against its 0.75 bar. All of it is unusable
while the reference the gates divide by is 6000 counts of leakage: a white
patch returning ~190 counts cannot be measured against a floor that drifts
by 175 between readings.

**The wiring lesson in finding 10 is not "check the pin rating".** It is that
an emitter with no off state keeps emitting, and what it does to whatever is
mounted next to it is not bounded by any current rating on the pin.

### Correction

The direct-cooling test above is not sound, and this finding should not be
read as proving damage. It reports `vcgencmd measure_temp`, which is the
**SoC** temperature -- the AS7341 sits on the optical head, remote from it.
The die's own temperature was never measured, so "4 C fall for a 5% drop"
compares a floor against a thermometer somewhere else.

Against it: **the floor was 0 at 2 a.m. and thousands by afternoon, on this
same sensor.** A permanently damaged part does not read zero.

The floor is real and it blocks every chemistry gate. Whether it is heat
damage or simply ambient temperature is **open**, and settling it needs a
thermometer on the sensor, or the same measurement repeated after dark.

---

## 16. A red dye PASSES G2 and G3 when the white reference collapses

**Severity: the gates report PASS, with confidence, on a measurement that
does not exist. This is the failure `BOUNTY.md` asks claimants to post.**

Measured, red dye in the well, this device, gain 256 / 916 ms:

```
dark         clear 5312
white patch  clear 5140      <- the REFERENCE read darker than darkness
sample       clear 5280

[FAIL] G1 return signal    -32000000.0000   limit 0.0150
[PASS] G2 cellular scatter  1e15            limit 2.2000   <- dye passed
[PASS] G3 haem Soret band   1.0000          limit 0.7500   <- dye passed
[FAIL] G4 spectral shape    0.0000          limit 0.9950
```

Not because the dye defeated the physics. Because `chemistry_gates()` forms
its ratios without ever checking that the white reference exceeds the dark
one. Once `white - dark <= 0`:

* **G2** divides by approximately zero and returns 1e15, which clears 2.2.
* **G3**'s index `(R630 - R415)/(R630 + R415)` goes to **1.0** as R415 goes to
  zero, which clears 0.75. A dead 415 channel is arithmetically identical to
  perfect Soret absorption.

G3's docstring anticipates exactly this and then does not act on it:

> Gate 1 has already established that the sample returns real signal, so the
> ratio is meaningful here.

That is an assumption recorded in a comment. `chemistry_gates()` evaluates all
four independently and returns a list; **G3 never checks whether G1 ran, let
alone passed.** The precondition its correctness depends on is documented and
unenforced.

### Why this is not just a broken-sensor story

The whole device still refuses this sample, because G1 and G4 fail and every
gate must pass. But a degraded white reference is not an exotic condition. A
dirty patch, an aged emitter, a cartridge inserted to the wrong stop, or a
sensor with elevated dark current (finding 15) all produce it. In each case
two of the four chemistry gates stop discriminating and start agreeing with
whatever they are shown.

A gate that fails loudly is safe. A gate that passes on garbage is not, and
these two pass in the direction that matters: **toward accepting a fake.**

### The fix

Refuse to evaluate rather than divide by a reference that is not there:

```python
if white_clear - dark_clear < MIN_REFERENCE:
    return GateResult(name, False, 0.0, threshold,
                      "white reference did not exceed dark -- nothing measured")
```

The gate set already has this instinct elsewhere: G5 checks speckle contrast
before it looks at motion, precisely so "no speckle" cannot read as "no
movement". G1-G4 need the same guard against "no reference" reading as
"perfect sample".

---

## Not changed

For the avoidance of doubt, these are untouched from `BUILD.md` §8/§9:

| | |
|---|---|
| Cartridge | 51 × 14 × 2.4 |
| Well | Ø4.0 × 0.55 deep, 10.5 from the tip |
| Moat | Ø7.0 annulus, 0.4 deep |
| White patch | 4 × 4, 3.0 from the tip, coplanar with the well rim |
| Aperture | Ø3.0 × 6.0 |
| LED angle / slant | 45° / 12 mm |
| Laser angle | 30° off normal |
| Camera slant | 20 mm, lensless |
| Travel / stops | 31.6 / 34.6 / 42.1 |
| Front slot | 34.0 × 3.0, baffle 6.0 behind |

`cad/spec.py` marks each of these `[OPTICS] — DO NOT EDIT`, and notes that the
fit checks deliberately will **not** catch damage to them: a bore at the wrong
angle still assembles perfectly and reads garbage.

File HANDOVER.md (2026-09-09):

# Handover

Everything an agent needs to pick this up cold. Written after two days of
bring-up, and organised so the expensive lessons arrive before you can repeat
them.

**Read "Traps" before touching hardware.** Most of them cost hours or parts.

---

## Access

```bash
ssh raspberrypi@192.168.1.22          # key auth, no password prompt
cd ~/Desktop/cell-4b                  # the deployed copy
.venv/bin/python -u <script>          # always the venv, always -u
```

The repo lives on the Mac at `/Volumes/Extreme SSD/Projects/cell/cell4b` and
is pushed to `github.com/nickthelegend/cell-4b`. The Pi copy is deployed with
`scp`, not `git pull` — keep them in sync by hand and `sync` after writing,
because this board loses power often enough to lose an unflushed file.

**The Pi reboots on its own.** `vcgencmd get_throttled` has reported
under-voltage. Expect SSH to drop mid-command; retry rather than diagnose.

**Long-running GUI processes die with the SSH session.** `nohup`/`setsid` did
not survive; hold the connection open instead:

```bash
ssh -o ServerAliveInterval=30 raspberrypi@192.168.1.22 \
  'cd ~/Desktop/cell-4b && DISPLAY=:0 XDG_RUNTIME_DIR=/run/user/1000 \
   WAYLAND_DISPLAY=wayland-0 exec .venv/bin/python -u gate_console.py'
```

Screenshots: `XDG_RUNTIME_DIR=/run/user/1000 WAYLAND_DISPLAY=wayland-0 grim
/tmp/x.png`. The display is **1520x651** — the console is laid out for it.

---

## Hardware state

| | GPIO | header | state |
|---|---|---|---|
| white #1 | 13 | 33 | working |
| **violet 400 nm** | 16 | 36 | working — **replaced white #2**, see below |
| 940 nm IR | 23 | 16 | working, **on +3V3** |
| laser 650 nm | 6 | 31 | working |
| cartridge switch | 22 | 15 | **never reads seated** — untrusted |
| ~~GPIO12~~ | 12 | 32 | **DEAD.** Killed by the 5V clamp, see trap 1 |

**AS7341 (0x39): high dark floor, cause not established.** It wanders between
826 and 5300 counts at gain 256 / 916 ms against a signal of ~200, and every
chemistry gate is a ratio against it. **That is the blocker.**

What is NOT established is why. Two candidates, and the evidence is mixed:

* **Ambient temperature.** Dark current roughly doubles every 8 C, and the
  floor was **0** at 2 a.m. and thousands by afternoon on the same hardware.
  That is a strong argument on its own.
* **Damage.** The 940 nm emitter sat lit against the die for hours before the
  rail error was found (trap 1), and NIR is the worst-affected channel.

An ice test appeared to rule out temperature, but it measured
`vcgencmd measure_temp` -- **the SoC, not the sensor** -- so it proved nothing
about the die. Do not repeat that mistake.

**To settle it:** measure the floor cold and hot with a thermometer ON THE
SENSOR, or simply take a reading after dark and compare against the same
reading at midday. If it tracks ambient, work cool; if it does not, replace
the part. FINDINGS 15 records the measurements, not a verdict.

**MAX3010x (0x57) and the OLED (0x3c) are fine.** The pulse gate works and has
authorised a real mainnet signature.

---

## Traps

### 1. A low-Vf emitter cannot be sink-driven from +5V

Sink drive puts the GPIO on the cathode, so "off" means driving the pin to the
anode's rail. A 3.3V pin cannot reach 5V, leaving `5.0 - 3.3 = 1.7 V` across
the LED. White LEDs (Vf ~3.0) do not care. **A 940 nm LED (Vf ~1.3) has no off
state**, and a released pin drives 5V through the ESD clamp into the 3.3V rail.

This killed GPIO12, and then it cooked the AS7341 sitting beside it.
**940 nm belongs on +3V3.** `hw.py`'s header said so all along.

### 2. EMITTER_OHMS is the calibration, not a comment

`atime_for()` scales integration time from it to hold collected light constant.
It says **220**; `hw.py` used to say 120. Every script that hardcoded
`atime=99` under-integrated by 1.8x and it presented as a dim instrument.
Derive it: `atime_for(EMITTER_OHMS)`.

### 3. `bench.white_2` is `None` when the violet is fitted

`WHITE2_IS_VIOLET = True` gives the violet white #2's bore and its pin — the
head has three LED bores and all were taken. Code that calls `white_2.on()`
directly raises. Use `with bench.white():`.

### 4. The gates PASS on a collapsed reference

`chemistry_gates()` divides by the white patch without checking it returned
any light. Once `white - dark <= 0`: G2 returns 1e15 and G3 returns 1.0,
**and both pass**. A red dye cleared them this way. FINDINGS 16.
`sign_with_blood` now refuses before the gates run; keep that guard.

### 5. A released sink pin lights its own LED

`gpiozero` releases pins to inputs on close, and an input floats. The emitter
then lights with nothing running. **Hold a `Bench` open for any dark
measurement** — `all_off()` drives the pins and holds them.

### 6. The Pi camera cannot see 940 nm

OV5647 has an IR-cut filter. A phone camera can (front camera is better than
rear). Do not conclude an IR emitter is dead from the Pi camera.

### 7. The Pi camera is LENSLESS

`spec.py` removes the lens deliberately for speckle. It cannot form an image —
frames are intensity maps. Do not expect a photograph of the chamber.

### 8. The white LEDs emit nothing at 415 nm

Blue-pump phosphor. 415 read a hard 0 at gain 128, 256 AND 512 while 445
doubled each time. **G3 is impossible without the violet emitter.** FINDINGS 12.

### 9. Other small ones

- `i2cdetect` is in `/usr/sbin`, off a normal user's PATH.
- `luma` blanks the OLED in `atexit` — pass `persist=True`.
- The USB QR camera **changes its node** on replug. Find it by driver:
  `/sys/class/video4linux/*/device/driver` == `uvcvideo`.
- The Adafruit AS7341 driver times out above `atime=182`.
- A **stale camera frame is worse than none** — it reads as working. The QR
  thread now reopens on stall and serves `None`.

---

## Signing

**Address `0xD9B4b074e48cfF75538E6468748C0FA2C16De5F5`.** Seed at `~/.cell/seed`
on the SD card — a hot wallet, accepted deliberately for bench work.

**On chain already:** `pulse.wei` registered on Ethereum mainnet, nonces 0 and
1, commit in block 25934252. Both authorised by the pulse gate.

### The airgap

The browser extension (`bridge/extension`, EIP-6963 as `life.proof.cell`) holds
**no key** — only the address. It builds an EIP-1559 transaction, frames it as
`pNofM <base64>`, and shows a QR. The device rebuilds it **from the fields**,
displays it, gates, signs, and shows the signature back as a QR.

Configure it in the extension popup: address, chain, gate, and **blind signing
on** for contract calls.

```
X   scan a QR from the USB camera, gate on PULSE, sign
B   run G1-G6 and sign only if all six pass
```

`/tmp/cell-frame.txt` is a frame handed over directly, for when the camera
cannot read the screen. Same payload, same rebuild, same gate — only the
transport differs. The signature is written to `/tmp/cell-signed.txt`.

### Two things that will bite

**Signature fields start at index 9** of the RLP, not 8 — index 8 is
`accessList`. Off by one recovers a valid signature for the *wrong address*.

**Signing is RFC 6979 deterministic**, so re-signing the identical transaction
reproduces the identical bytes. That is how a signature was recovered after the
console failed to display its QR — it is the same signature, not a new one.

---

## Where it stands

**Working:** device assembled and running; pulse gate; airgapped bridge; blind
signing with a calldata hash; both whites; the 940 nm on the right rail; the
400 nm violet with a clean 415 channel (6.5x selectivity, no housing
fluorescence); two-position reads when the sensor holds still.

**Blocked:**

- **Chemistry gates** — the AS7341's dark floor swamps the signal. Establish
  whether it tracks ambient temperature before assuming the part is at fault;
  it read 0 at 2 a.m. on this hardware.
- **G5/G6** — speckle contrast `K = 0.073` against a 0.10 floor, flat across a
  66x exposure sweep. Grain size, not exposure. FINDINGS 14.
- **G3** — needs the violet, which is now fitted. Measured a red dye at
  **0.2233** against its 0.75 bar with a real two-position read.

**The bounty** (`../BOUNTY.md`, poidh 24) wants four things and three are done:
device running, a pulse-authorised signature, and a transaction on chain.
Blood is not. It also says **"a failure is a claim too"** — and FINDINGS 13,
14, 15 and 16 are exactly that, measured on this hardware.

## Rules that held

- **Never fake a gate result.** A green screen that did not happen is worth
  less than a documented refusal, and the whole claim of the instrument is
  that its numbers are honest.
- **A gate that passes on garbage is worse than one that fails.** Prefer
  refusing to measure over reporting a number nobody can defend.
- **Say which reading is untrustworthy and why.** Most of the wasted time here
  came from treating a broken measurement as data.

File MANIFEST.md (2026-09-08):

# CELL-4B printed parts

Generated by `cad/build.py`. Every number is interpolated from `cad/spec.py`, so this file cannot drift from the STLs beside it. Do not hand-edit -- regenerate.

| Part | Qty | Triangles | Volume | Size (mm) | Material | Settings | Orientation |
|---|---|---|---|---|---|---|---|
| `cartridge` | 20 | 580 | 1852 mm3 | 14.0 x 51.0 x 3.6 | white PLA | 0.15 mm, 3 perim, 100%, IRONING ON | well-side up, no supports |
| `cartridge_reference` | 1 | 308 | 1862 mm3 | 14.0 x 51.0 x 3.6 | white PLA | as cartridge | well-side up |
| `cartridge_null` | 1 | 36 | 1869 mm3 | 14.0 x 51.0 x 3.6 | white PLA | as cartridge | flat, no supports |
| `optical_head` | 1 | 98700 | 30891 mm3 | 57.06 x 60.78 x 31.0 | black PLA | 0.12 mm, 6 perim, 40% | legs down, no supports (it bridges 17.8 mm over the cartridge channel); paint ALL bores matte black; HOT-GLUE the three legs to the case floor |
| `slot_baffle` | 1 | 28 | 21 mm3 | 5.59 x 2.4 x 1.6 | black PLA | 0.16 mm, 4 perim, 100% | flat |
| `window_jig` | 1 | 252 | 6096 mm3 | 60.0 x 42.0 x 3.0 | any | 0.2 mm, 2 perim, 20% | flat; not a device part |
| `shell_lower` | 1 | 52468 | 54308 mm3 | 92.0 x 128.0 x 28.0 | black PLA | 0.16 mm, 4 perim, 25% | open side up, no supports |
| `shell_upper` | 1 | 14260 | 65057 mm3 | 92.0 x 128.0 x 33.8 | black PLA | 0.16 mm, 4 perim, 25% | TOP FACE DOWN, no supports |
| `oled_bezel` | 1 | 592 | 1141 mm3 | 38.5 x 36.5 x 1.2 | black PLA | 0.12 mm, 4 perim, 100% | flat, front face down |

## Plates (Bambu P1S, 256 mm bed, 250 mm usable)

| # | Plate | Footprint | Fits | Contents |
|---|---|---|---|---|
| 1 | Plate 1 - shells | 196.0 x 182.0 mm | yes | shell_lower x1, shell_upper x1, window_jig x1 |
| 2 | Plate 2 - optics | 125.1 x 60.8 mm | yes | optical_head x1, slot_baffle x1, oled_bezel x1 |
| 3 | Plate 3 - cartridges | 248.0 x 177.0 mm | yes | cartridge x20, cartridge_reference x1, cartridge_null x1 |

## Filament

- black PLA: 151.4 cm3 solid, ~188 g at 100% (much less at the infills above)
- white PLA: 40.8 cm3 solid, ~51 g -- cartridges print at 100%, so take this one as real

**One white spool, one session, ironing ON.** The white patch on every cartridge is the photometric reference every gate normalises against; switching filament mid-batch walks your thresholds without telling you.

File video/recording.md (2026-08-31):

# CELL-4B demo — scene map

One scene per beat. Each records to its **own** video file, so any single scene
can be re-recorded or re-timed without touching the rest.

Recorded by driving the real viewer in a headless Chromium via Playwright's
`recordVideo`. Only the browser viewport is captured — nothing touches the
desktop. Every click and dropdown change is a real interaction against the real
`out/manifest.json` and the real GLBs; no staged screenshots, no faked numbers.

Viewport 1440 × 900, 30 fps.

| # | id | What happens | Narration beat |
|---|---|---|---|
| 01 | `intro` | Animated title card built in the page: CELL-4B wordmark draws in, subtitle fades up | What this is |
| 02 | `problem` | Assembled view, slow orbit | A Pi 4B enclosure for a blood-reading hardware wallet |
| 03 | `why_4b` | Assembled view, camera pushes toward the Pi through the shell | Why a 4B and not upstream's Pi Zero |
| 04 | `finding` | Sidebar note about the 28 mm standoff highlighted, then the optics panel | The 9 mm standoff cannot be built |
| 05 | `cutaway` | Switch to Cutaway, orbit, then hide the head to reveal the camera | Where the camera actually is |
| 06 | `ribbon` | Cutaway with the CSI ribbon isolated, orbit along its route | The ribbon had nowhere to go |
| 07 | `clearance` | Scroll the placement + clearance panels | Every component measured |
| 08 | `steps` | Step through build steps 1 → 10 in the dropdown | How it goes together |
| 09 | `explode` | Exploded view, slow orbit | The whole stack |
| 10 | `plates` | Plate 1 → Plate 4 | What you actually print |
| 11 | `audit` | Badge close-up, then the checks summary | 309 checks, 0 failed |
| 12 | `outro` | Animated end card: repo URL wipes in | Where to get it |

## Rules

- **No staged results.** The audit badge shows whatever the manifest says. If a
  check fails, the video shows it failing.
- **No console errors in frame.** The recorder asserts a clean console per
  scene and fails the run otherwise.
- **Pacing is driven by audio.** Each scene's clip is retimed to its measured
  Kokoro duration — speed-ramped if the footage runs long, last frame held if
  it runs short. Durations are measured from the generated WAV, never estimated.
- **Length first, speed after.** The full cut is assembled at 1×. `scenes.json`
  then carries a per-scene multiplier so runtime can be cut without cutting
  content: `python3 video/rerender.py`.

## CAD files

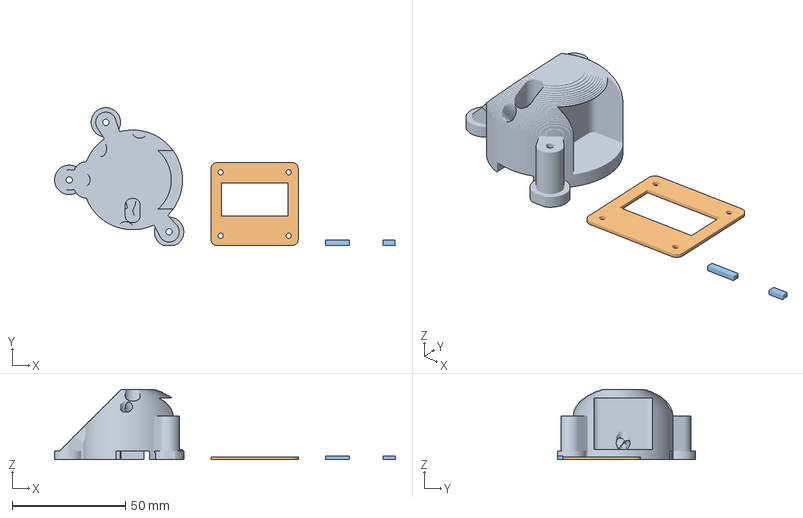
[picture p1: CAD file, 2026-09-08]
out/reprint_optics.3mf
150.4 x 60.8 x 31.0 mm
optical_head_1
oled_bezel_1
slot_baffle_1

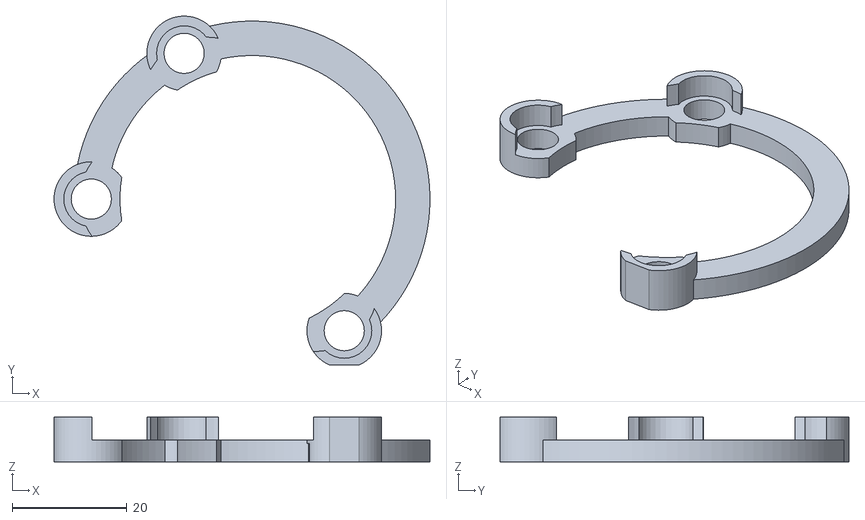
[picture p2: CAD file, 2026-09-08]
out/stl/head_chair.stl
65.5 x 60.8 x 7.80

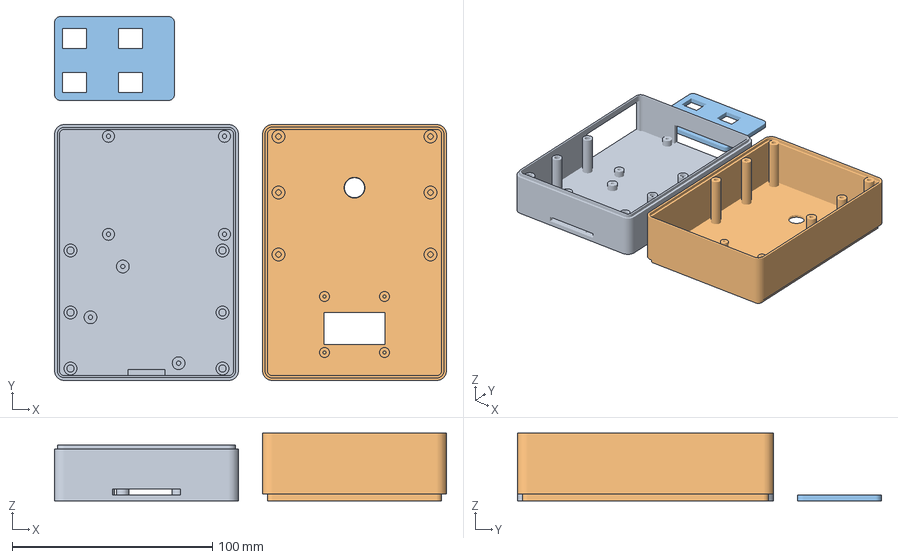
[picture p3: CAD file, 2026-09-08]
out/plate1.3mf
196.0 x 182.0 x 33.8 mm
shell_lower_1
shell_upper_1
window_jig_1

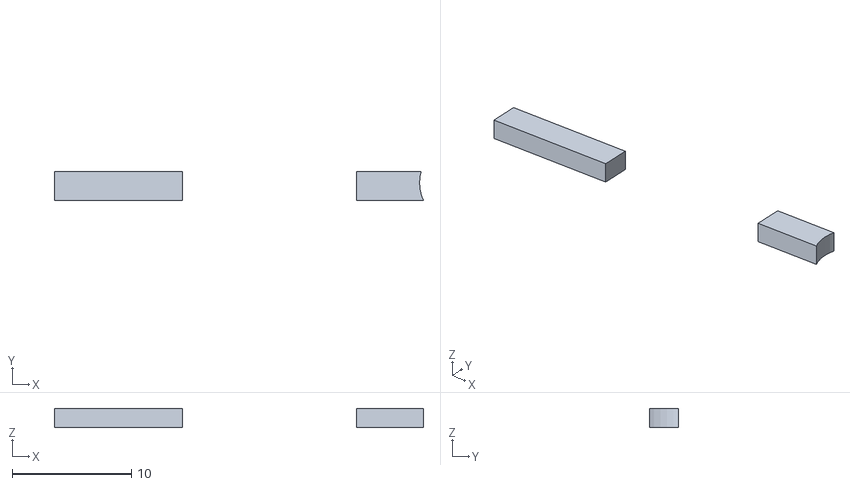
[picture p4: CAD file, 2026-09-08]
out/stl/slot_baffle.stl
30.9 x 2.40 x 1.60

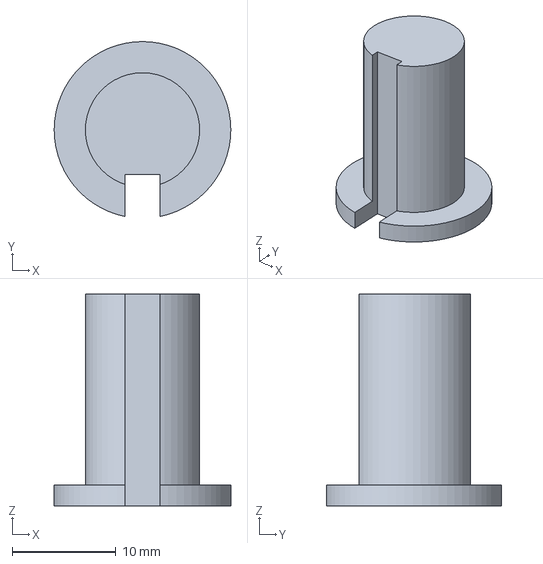
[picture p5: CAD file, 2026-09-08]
out/reprint_touchpost.3mf
17.0 x 16.8 x 20.4 mm

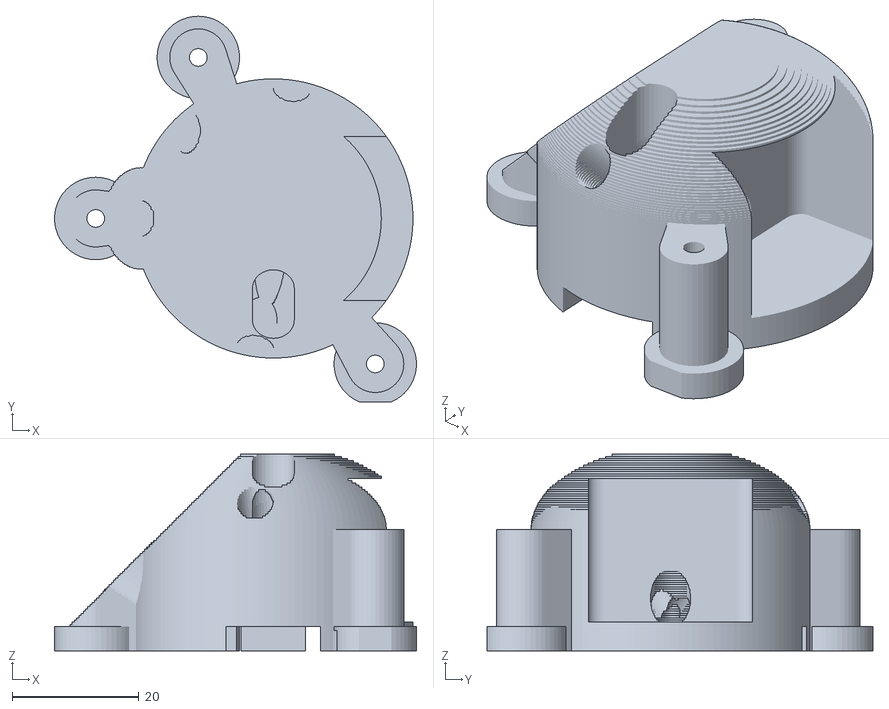
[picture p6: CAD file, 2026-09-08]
out/stl/optical_head.stl
57.1 x 60.8 x 31.0

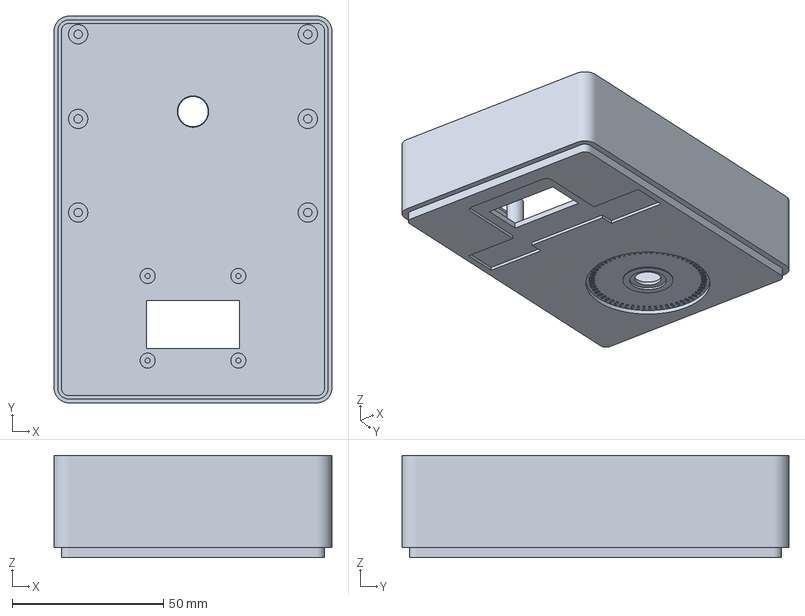
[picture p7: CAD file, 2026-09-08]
out/reprint_top.3mf
92.0 x 128.0 x 33.8 mm

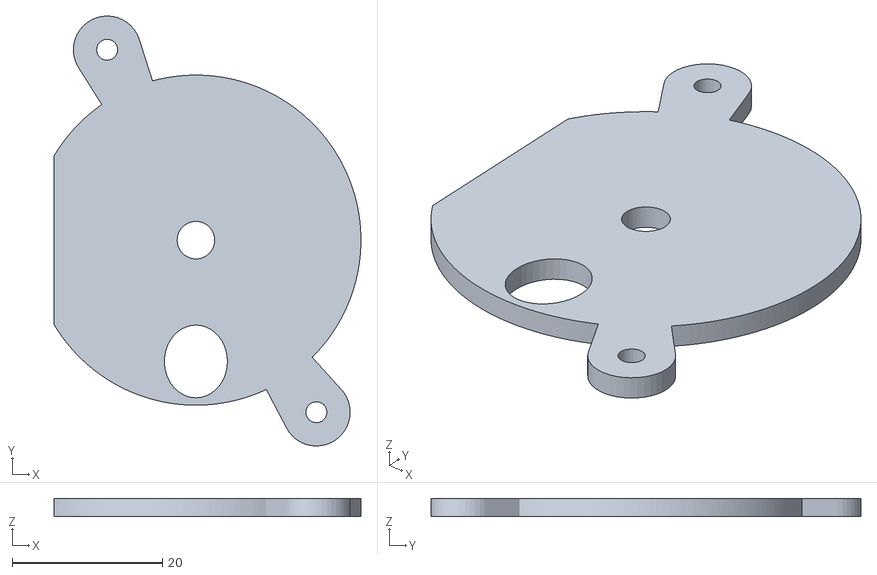
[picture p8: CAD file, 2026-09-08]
out/stl/sensor_deck.stl
40.9 x 57.3 x 2.40

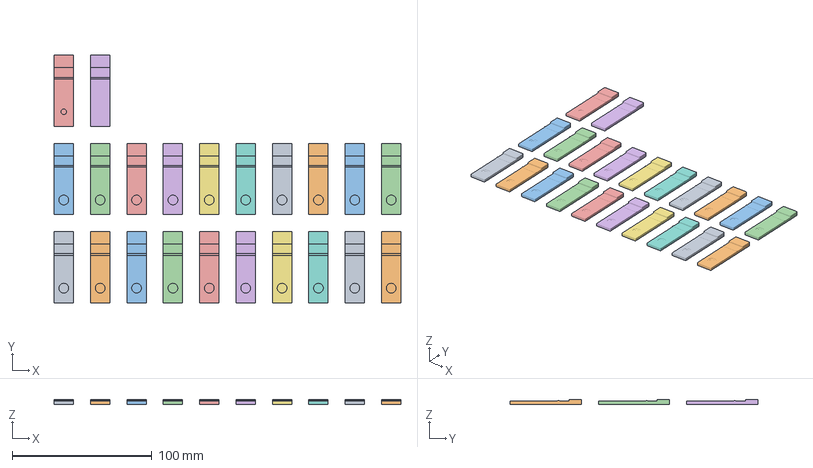
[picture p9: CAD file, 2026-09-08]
out/plate3.3mf
248.0 x 177.0 x 3.60 mm
cartridge_1
cartridge_2
cartridge_3
cartridge_4
cartridge_5
cartridge_6
cartridge_7
cartridge_8
cartridge_9
cartridge_10
cartridge_11
cartridge_12
cartridge_13
cartridge_14
cartridge_15
cartridge_16
cartridge_17
cartridge_18
cartridge_19
cartridge_20
cartridge_reference_1
cartridge_null_1

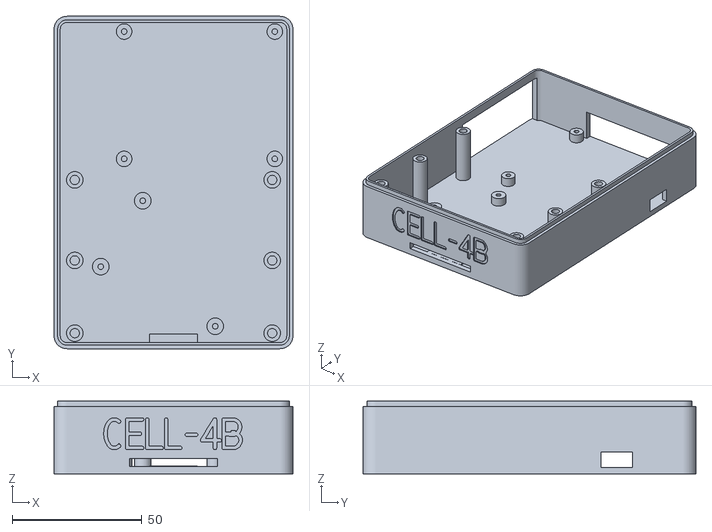
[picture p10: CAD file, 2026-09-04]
out/stl/shell_lower.stl
92.0 x 128.0 x 28.0

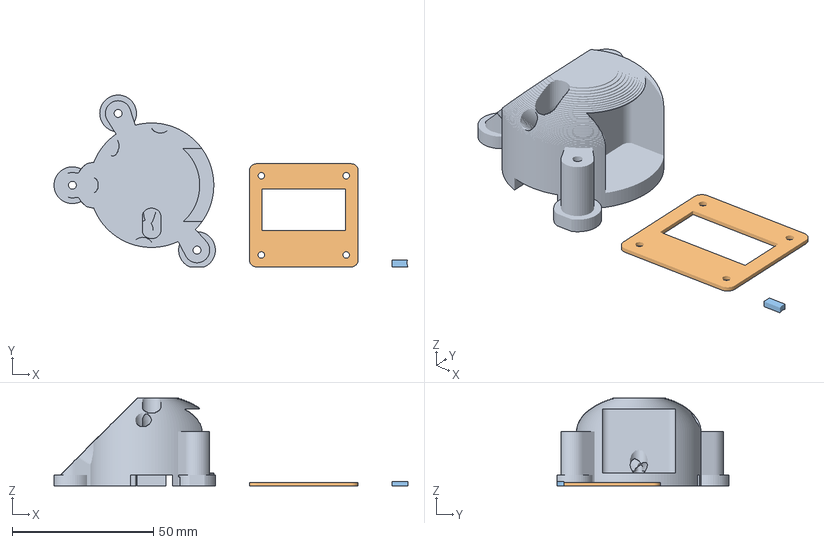
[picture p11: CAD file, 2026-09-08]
out/plate2.3mf
125.1 x 60.8 x 31.0 mm
optical_head_1
oled_bezel_1
slot_baffle_1

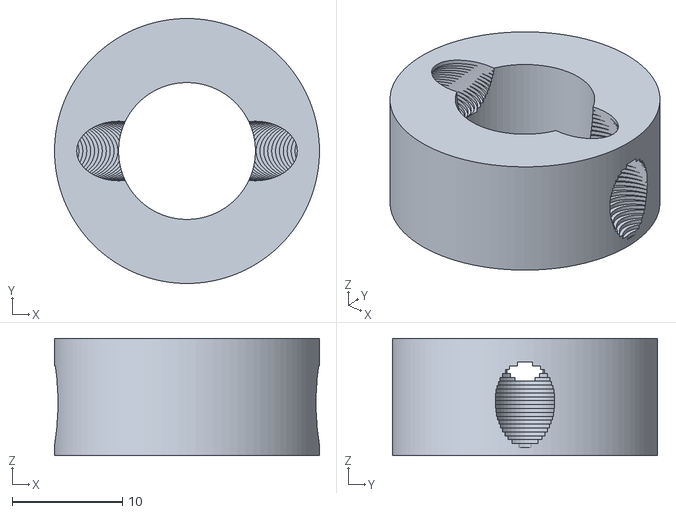
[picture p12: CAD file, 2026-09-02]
out/stl/touch_collar.stl
24.0 x 24.0 x 10.6

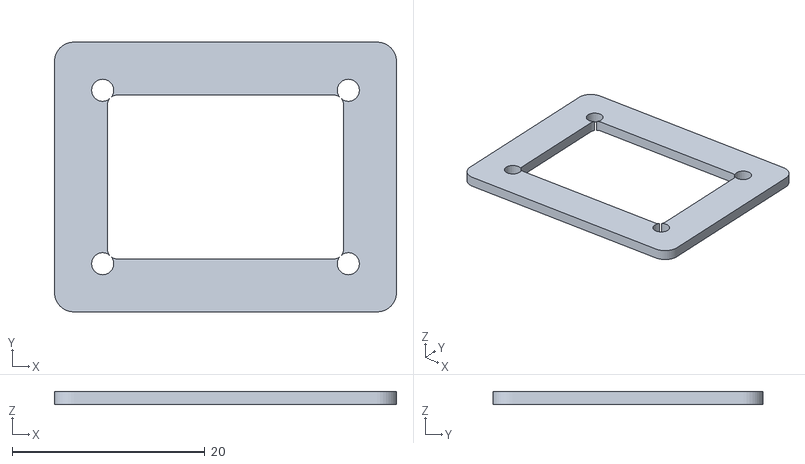
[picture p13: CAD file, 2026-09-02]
out/stl/sensor_carrier.stl
35.5 x 28.0 x 1.40

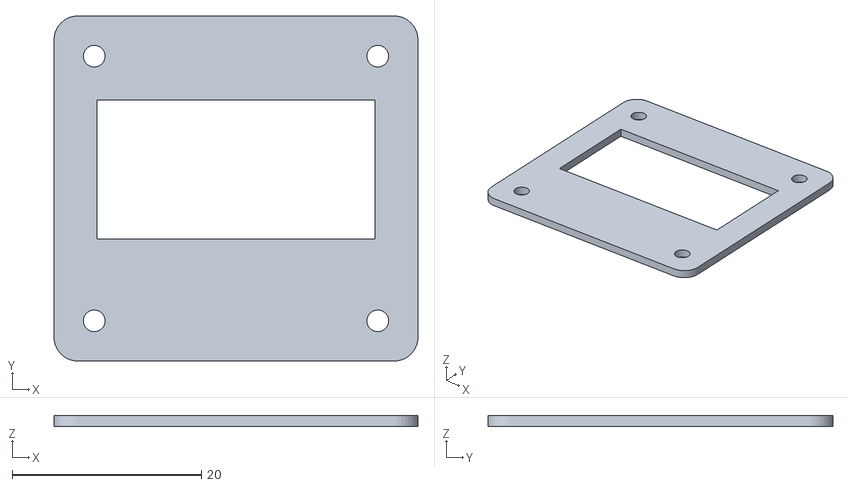
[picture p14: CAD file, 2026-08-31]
out/stl/oled_bezel.stl
38.5 x 36.5 x 1.20

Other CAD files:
out/stl/shell_upper.stl
out/stl/cartridge_null.stl
out/stl/aperture_tube.stl
out/stl/cartridge_reference.stl
out/stl/cartridge.stl
out/stl/window_jig.stl

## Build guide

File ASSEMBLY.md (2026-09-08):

# CELL-4B assembly

Open the viewer alongside this; every step names the part as it appears in the
parts list.

```bash
cd cell4b && python3 -m http.server 8731
# then http://localhost:8731/viewer/index.html
```

Coordinates: **X** right, **Y** back, **Z** up. The **front** (−Y) is the
cartridge slot. The **back** (+Y) carries the Pi's USB-C, HDMI and audio.

---

## 0. Before you print

**Measure these five and edit `cad/spec.py`, then re-run the build.** They are
the ones I could not confirm against a datasheet, and they are marked `VERIFY`
in the file:

| Constant | Default | What to measure |
|---|---|---|
| `OLED_PCB_L/W`, `OLED_HOLE_DX/DY` | 35.5 × 33.5, 30 × 28 | 1.3" 4-pin OLED modules vary by vendor more than any other part here |
| `OLED_ACTIVE_OFF_Y` | 2.0 | glass centre offset from PCB centre, away from the pins |
| `CAM_HOLE_DX/DY` | 21.0 × 12.5 | your OV5647 clone's mounting holes |
| `AS_HOLE_DX/DY` | 25.5 × 18.0 | Waveshare AS7341 hole pitch |
| `LASER_BODY_D/L` | Ø6 × 10 | the brass barrel on your module |
| `PI_SD_H` = 2.0 | how far the microSD hangs below the board — not on the official drawing |
| `CAM_PCB_L/W` | 25 × 24 | sets the drop-in pocket the camera lowers into |

```bash
python3 cad/build.py     # re-runs the audit, then rewrites STLs + plates
```

The build **refuses to write** if any check fails, so a plate that reaches your
slicer has already passed all 304.

---

## 1. Print

Four plates, all inside the P1S bed. `MANIFEST.md` carries the settings table.

| Plate | Parts | Filament |
|---|---|---|
| 1 | `shell_lower` | black |
| 2 | `shell_upper` | black |
| 3 | `optical_head`, `sensor_deck`, `aperture_tube`, `slot_baffle`, `oled_bezel`, `sensor_carrier`, `window_jig` | black |
| 4 | 20 × `cartridge` + `cartridge_reference` + `cartridge_null` | **white** |

Three rules that are not style preferences:

1. **Plate 4 in one session, from one white spool, ironing ON.** The 4 × 4 mm
   patch on every cartridge is the photometric reference every gate normalises
   against. Switching filament mid-batch walks your thresholds silently.
2. **Cartridges well-side up, no supports.** The well floor and the patch must
   both be top surfaces or ironing does nothing for them.
3. **`aperture_tube` flange DOWN.** The flange seats in the head's counterbore
   and the barrel hangs at the standoff, rather than being glued at it.

Then **paint every bore in `optical_head` and `aperture_tube` matte black**,
and the inside of the head's chamber. This is not cosmetic: §9's light-tightness
test is Clear < 0.5 % of LEDs-on at 10,000 lux, and thin dark PLA passes more
light than you expect.

---

## 2. Lower shell

1. Four **M2.5 × 6 self-tapping** screws hold the Pi. The bosses are already at
   the 58 × 49 mm pitch — check with calipers before you force anything.
2. Drop the **Pi 4B in GPIO-header-forward**: the header faces the front (−Y),
   toward the optical head, so the jumper runs are short. USB-C, HDMI and audio
   end up at the back wall; Ethernet and USB on the left; microSD on the right.
3. Press `slot_baffle` into its slot behind the front mouth, 6 mm back.
4. Four **M2.5 heat-set inserts** into the corner bosses, 6 mm deep.

## 3. Optical head — the part that matters

Fit everything into the head **before** it goes into the shell, and before
`sensor_deck` caps it. Once the deck is on, the LED bores are unreachable.

1. **Three LEDs**, from outside, into the three 45° side bores:
   - azimuth **82°** — white LED #1
   - azimuth **262°** — white LED #2 (opposed, cancels droplet shading)
   - azimuth **135°** — **940 nm IR**
   Push each until the dome bottoms at slant 12. Leads trail out behind.
2. **Laser** into the 30° bore at azimuth **270°**. This is the one bore that
   leaves through the **top** face, which is why the AS7341's narrow side has
   to face 90/270 — do not rotate the board.
3. **Camera** on the 45° bore at azimuth **0°**, lens **removed**, sensor
   facing the spot at 20 mm. It ends up **inside** the head, in a drop-in
   pocket cut for it — lower it straight down before the deck goes on.
4. **Route the CSI ribbon before the deck goes on.** This is the step that is
   easy to leave until too late. The camera sits at r = 14.1 mm from the read
   spot — **inside** the Ø44 head — so 96% of it is buried and its ribbon
   starts in a blind pocket. It leaves through the head's +X side wall, turns
   **on edge** to drop down the channel between the head and the case wall,
   crosses the 12 mm gap between the head and the Pi still on edge, then lies
   **flat** again and goes up and over the GPIO header into the CSI socket.
   That is a **110 mm** run; a 150 mm ribbon is comfortable, a 100 mm one will
   not reach. `cad/spec.py: CABLE_ROUTE` has the waypoints and
   `audit.check_cable_route()` verifies the whole corridor is clear.
5. **`aperture_tube`**, flange up, into the central counterbore.
6. **`sensor_deck`** on top. Its three **ears** line up with the head's three
   lugs — see below. Nothing screws down through the middle of the deck, so
   the AS7341 lands on a flat face.
7. **AS7341** on `sensor_carrier`, chip **DOWN** over the relief shaft, then
   onto the deck. **Long axis along X.**

Then drop the head onto the **three lugs** in `shell_lower` and screw down.
Its skirt closes to 0.2 mm above the cartridge, everywhere except the corridor
the cartridge itself sweeps.

**Three lugs, not four, and they are outside the head — not through it.** The
fastening used to run through the optical body and could not be built: two of
the four posts opened straight into the camera pocket, and all four left
0.08 mm of wall to an LED bore where the minimum is 1.0. Four interior
positions are impossible at any radius, because the camera pocket and the 45°
LED bore between them own that whole quadrant. So the screws moved out:

| Lug | Azimuth | Clearance to the nearest thing |
|---|---|---|
| 1 | **115°** | 2.5 mm (the CSI ribbon owns +Y, which is why not 90°) |
| 2 | **180°** | 12.8 mm |
| 3 | **305°** | 5.9 mm (only free because the switch moved to −X) |

One M2.5 per lug runs **deck ear → head lug → shell boss**, so a single screw
column clamps the whole stack and never crosses a bore. Three is also the right
number: it cannot rock, and the read spot sits inside the triangle they form.
See `FINDINGS.md` §9.

### Buy these, and do not over-torque them

The screw column is 33.4 mm of stack, so the lug screws are **long**:

| Screw | Length | Passes through | Threads into | Engagement |
|---|---|---|---|---|
| Head lugs × 3 | **M2.5 × 35** | deck ear 2.4 + head lug 27.2 | shell boss | **3.8 mm** |
| AS7341 × 4 | **M2 × 8** | carrier 1.4 + board 1.6 | sensor deck | **2.4 mm** |
| Pi × 4 | M2.5 × 6 | — | shell bosses | 4.0 mm |
| Lid × 4 | M2.5 × 8 | counterbores | shell bosses | — |

Engagement on the lugs is 1.5 × diameter and on the AS7341 1.2 ×, which is
below the usual 2 × rule. The loads are grams, so it holds — but these are
self-tapped into PLA, so run them in **by hand** and stop at first resistance.
A stripped boss is not repairable. `audit.check_screws()` recomputes every
number in this table from the geometry, so it cannot drift from the parts.

The microswitch sits on the **−X** side of the slot. It moved there to free
the 305° lug; the cartridge channel is symmetric, so nothing else changed.

**Wire the laser interlock in hardware.** The cartridge microswitch contacts go
**in series with the laser module's supply**, not in the GPIO6 gate line. An
interlock the firmware can talk its way past is not an interlock.

## 3b. Touch tier — the flip-mount

The **same AS7341** serves both tiers. Which one you are building decides which
way up it goes:

| Tier | Board | Reads |
|---|---|---|
| **Blood** | chip **DOWN** on the deck at Z 35.8 | the cartridge, down the relief shaft |
| **Touch** | chip **UP** at Z 37.4 | a fingertip, up the ring port |

`sensor_carrier` is symmetric — same four M2 holes either way round — so it
clamps the board in both orientations without a second part.

For touch, add:

1. **`touch_collar`** on top of the carrier. Two 45° bores, inserted from
   outside:
   - azimuth **0°** — white LED (this is the red channel)
   - azimuth **180°** — **940 nm IR**
   Push each until it bottoms at slant 12, same as the blood LEDs.
2. **Ø10 × 0.5 window** into the Ø10.4 × 0.6 rebate at the ceiling's **inner**
   face — it goes in from underneath, and it seals the chamber.

The finger presses on that glass through the ring bore. The port is a
**through-hole**: one optical axis serves the finger above and the cartridge
below, which is how upstream cuts it too.

Wire the touch LEDs to their own GPIOs — the blood LEDs point the other way and
cannot be shared.

## 4. Upper shell

1. **OLED** on the four posts under the ceiling, glass up to the window.
2. **`oled_bezel`** into the top-face recess — it masks the window down to the
   29.42 × 14.7 mm active area.
3. **Ø10 × 0.5 window** into the seat at the bottom of the finger well.
4. Close the lap joint and four M2.5 × 8 through the counterbores.

## 5. Wiring

The firmware is set to the **SINK** build (`hw.EMITTER_SINK = True`) — commit
`d514af1`, so a build with no transistors works. This table is that build, with
the **220 Ω** resistors actually fitted. **The flag must match your solder
joints** — get it wrong and every emitter is lit exactly when it should be dark.

| Pin | Function | Wiring |
|---|---|---|
| GPIO2/3 | I²C1 — AS7341 **0x39**, MAX30100 **0x57** | SDA / SCL, shared |
| GPIO12 | white LED #1 | +5 V → **220 Ω** → LED → GPIO12 (**pin sinks; LOW = lit**) |
| GPIO16 | white LED #2 | +5 V → **220 Ω** → LED → GPIO16 |
| GPIO23 | 940 nm IR | **+3V3** → **220 Ω** → LED → GPIO23 |
| GPIO6 | laser ENABLE | TTL enable on the module; module power straight off +5 V |
| GPIO22 | cartridge switch | internal pull-up, LOW when seated |
| CSI | camera | ribbon |

### The resistor is not a free choice — it is what makes a sink build legal

In a sink build the **GPIO carries the LED current**, and a Pi pin is rated
16 mA. The 68/47 Ω the optical design asks for assume a transistor in the
ground return; put them on a pin directly and they blow straight past it:

| | sink (as built) | with a 2N7000 |
|---|---|---|
| white, 68 Ω on +5 V | **27.9 mA — over the pin limit** | 25.3 mA |
| white, **120 Ω on +5 V** | **15.8 mA** ✓ | 15.0 mA |
| 940 nm, 47 Ω on +3V3 | **41.5 mA — over the pin limit** | 36.1 mA |
| 940 nm, **120 Ω on +3V3** | **16.2 mA** — 0.2 over, see below | 15.4 mA |

So the fitted resistor is load-bearing: **do not "correct" it back to 68/47
while `EMITTER_SINK = True`.** Fitting the design resistors means fitting
transistors in the same session, and setting the flag to `False`.

**Integration is derived from the resistor, not hard-coded.** Set
`spectro.EMITTER_OHMS` to what is actually soldered and `atime_for()` scales the
timing with it — current goes as 1/R, so the sensor stays open in proportion:

| fitted | ATIME | integration |
|---|---|---|
| 120 Ω | 99 | 500 ms |
| 150 Ω | 124 | 626 ms |
| **220 Ω** | **182** | **916 ms** |
| 240 Ω | 199 | 1001 ms |

The two must move together. 220 Ω timing on 120 Ω hardware over-integrates
1.8× and saturates; the reverse under-reads. Above ~307 Ω the ATIME register
runs out at 255 and ASTEP has to rise too.

Halving the drive current and doubling the integration collects **the same
photons**, so shot-noise-limited SNR is unchanged — what a bigger resistor costs
is read *time*, and the part can integrate for 46.6 s. 916 ms is under 2 % of
that. LEDs at 9 mA also run far cooler than at 28, which makes M2's
"< 1 % RSD over 100 reads" easier to hit, not harder.

**The IR must stay on +3V3 — for the pad, not the brightness.** A sink LED lets
its GPIO float to (rail − V<sub>f</sub>) whenever the pin is an input, which it
is during boot. A white on +5 V floats the pin to 1.90 V, fine. The 940 nm
part's V<sub>f</sub> is only 1.35 V, so from +5 V it would float the pin to
**3.65 V**, over the 3.3 V pad limit. Never move the IR to the 5 V rail here.

### MAX30100 — the touch tier, on the same two I²C wires

It is the **only** part the touch tier needs. It joins the bus the AS7341 is
already on, and the addresses do not collide, so there is no mux:

| MAX30100 pin | goes to | note |
|---|---|---|
| VIN | **3V3** | the breakout regulates down to the chip's 1.8 V itself |
| GND | GND | |
| SDA | **GPIO2** | same wire as the AS7341 |
| SCL | **GPIO3** | same wire as the AS7341 |
| INT | *not connected* | polling is enough at 50 Hz |
| IRD / RD | *not connected* | LED drive is internal |

Four wires. **Solder them flat to the pads — do not fit the pin header.** A
header is 8–10 mm tall and `touch_post` leaves 23.0 mm between the head's flat
top and the finger well, of which the board and chip already take 2.6. Route
them down the 3.4 mm channel in the post's side.

**If `i2cdetect` does not show `0x57`, check the pull-ups first.** The common
GY-MAX30100 breakout ties its I²C pull-ups to the chip's internal **1.8 V**
rail rather than to VIN, which is enough to stop a 3.3 V Pi seeing it at all.
It is a well-known board fault with a well-known rework, and it looks exactly
like a dead sensor. Check this before you suspect the part.

Note also that this is now a **second** set of pull-ups on the bus, against the
"only one 2.2 kΩ pair" rule below. Two pairs in parallel halve the effective
resistance; the bus is short and slow enough here that it works, but if the
AS7341 starts misbehaving after the MAX goes on, that is where to look.

### A hand-held tactile switch on GPIO22 is a valid build

The slot switch does not exist yet, and a tactile switch cannot replace the
lever microswitch *in the slot* — its 0.25 mm travel is shorter than the
channel's own fit clearance, it would be side-loaded, and its 6 mm body leaves
~8.6 mm of the baffle notch open against a 1.2 mm daylight budget.

But **held in the hand it is a legitimate enable**, and for everything up to M5
it needs no changes at all: the wiring is identical, and `Button(pull_up=True)`
reads a tactile to ground exactly as it reads a lever.

For M6 it must be **HELD, not pressed once.** `laser()` used to check the switch
only on entry, and `Speckle.series()` holds that block open for 600 s — so a
momentary press bought a ten-minute exposure. The beam now **follows the switch
for the whole block**: release it and the laser drops immediately, and the run
raises rather than quietly returning dark frames.

That makes a held button a deadman, which is a real safety device. A latched or
taped-down one is not — it is `BENCH_NO_INTERLOCK` with extra steps.

**The laser is not sunk.** It needs 20–40 mA, far past a pin's 16 mA, so it is
never driven the way the LEDs are — it is a module with a TTL ENABLE input
taking its current straight off +5 V. Its gate line is always active-high
regardless of `EMITTER_SINK`.

Only **one** 2.2 kΩ pull-up pair on the I²C bus. With a single breakout you
keep the one it ships with — the classic first-build failure needs two boards
fighting each other, which does not apply until you add the ATECC.

---

## 6. First light

```bash
sudo raspi-config          # Interface Options -> I2C -> enable
sudo i2cdetect -y 1        # AS7341 answers at 0x39
```

Then work the milestones in upstream `BUILD.md` §15:

- **M2** — AS7341 on a white card, < 1 % RSD over 100 reads
- **M3** — 20 cartridges, < 3 % white-patch spread. Fix your printer here
- **M4** — chamber light-tight, Clear < 0.5 % at 10,000 lux
- **M5** — **415 nm separates red food dye from your blood.** The "it works"
  moment, and the first thing this whole build exists to answer
- **M6** — 600 s speckle series, both classes
- **M7** — spoof panel, `thresholds.json`, ROC. This is the partial claim

Because the sensor sits at 28 mm rather than 9 mm, **raise `ATIME`/`ASTEP`
before M2** and confirm the 415 nm channel is comfortably off the ADC floor on
a white card. If it is not, say so in the writeup — that is a result.

Read upstream `SAFETY.md` before any of this involves blood. One device, one
person, one lancet per use, sharps container.

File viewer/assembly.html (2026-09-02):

CELL-4B

assembly, component by component

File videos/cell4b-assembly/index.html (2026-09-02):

CELL-4B

assembly, component by component

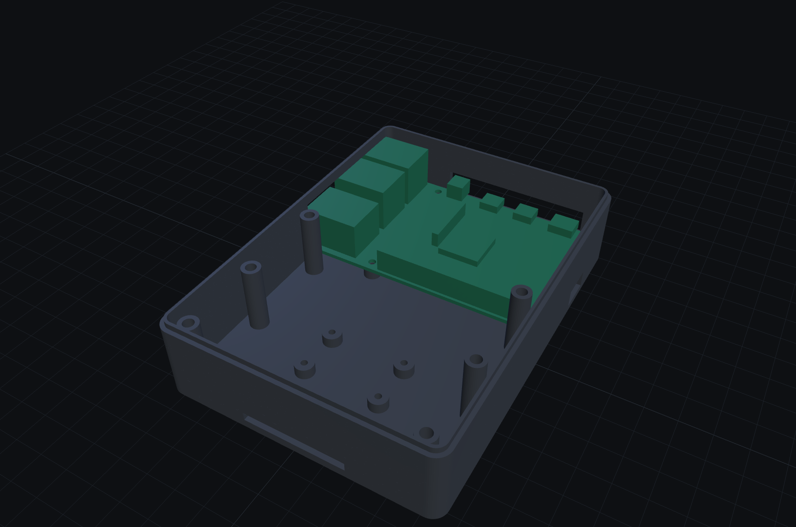
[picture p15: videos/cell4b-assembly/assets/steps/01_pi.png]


01 / 13

Raspberry Pi 4B

WHERE(0, 33.6, 6.4)

HOW4 x M2.5 into the 58 x 49 bosses

GPIO header faces the FRONT, toward the optics

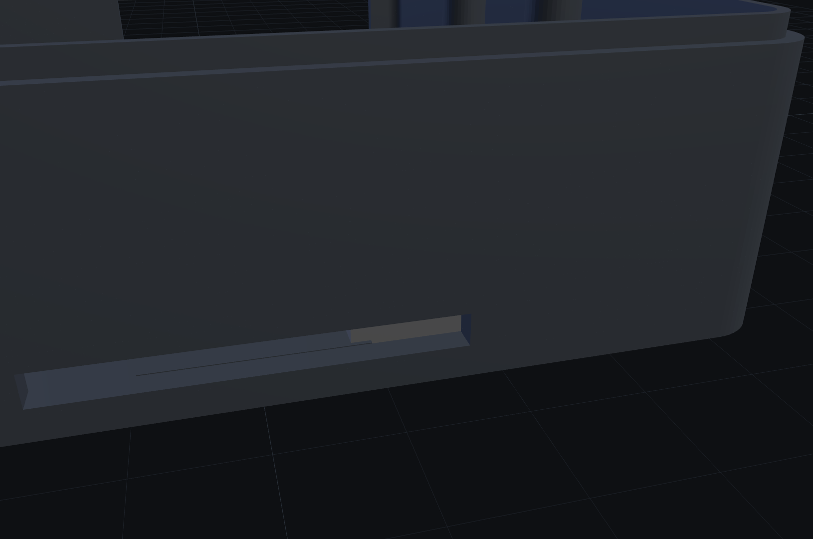
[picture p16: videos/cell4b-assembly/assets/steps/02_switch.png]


02 / 13

Cartridge switch

WHERE(14.0, -58.2, 2.4)

HOWlever into the cartridge channel

ALSO the laser interlock — wire it in series with the laser supply

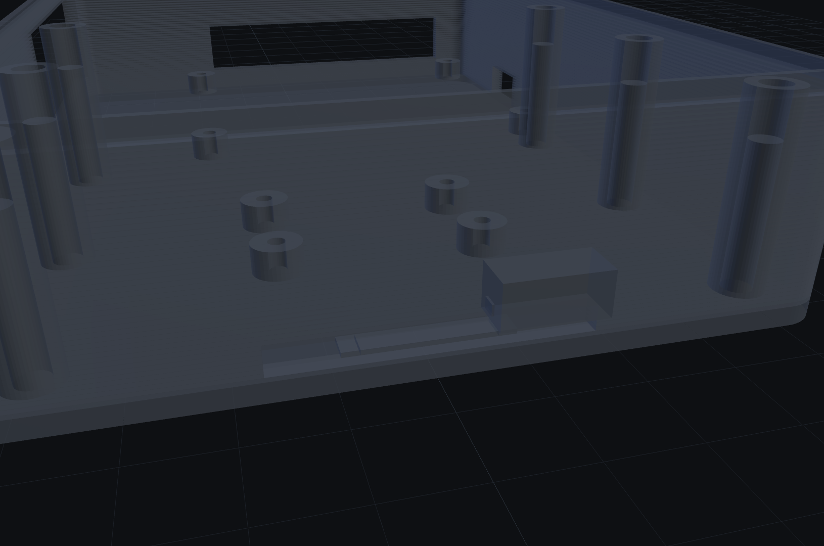
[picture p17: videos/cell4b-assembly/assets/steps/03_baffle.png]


03 / 13

Slot baffle

WHERE6 mm behind the slot mouth

HOWpress fit, notch over the switch

stops 1 mm below the head skirt — together they are light-tight

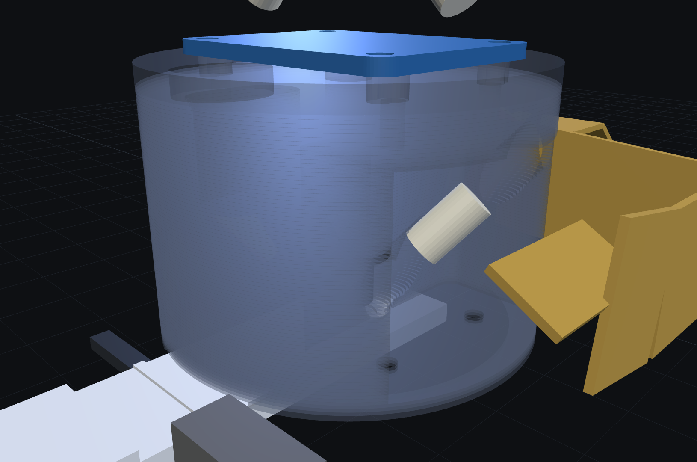
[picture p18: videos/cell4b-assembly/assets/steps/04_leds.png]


04 / 13

White LEDs + 940 nm IR

WHERE45°, 12.00 mm from the read spot

HOWfrom OUTSIDE, into the three side bores

azimuth 45 and 225 for the whites, 135 for the IR

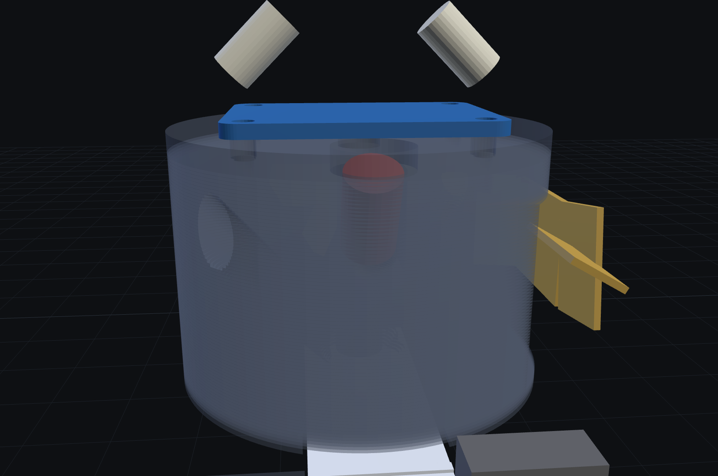
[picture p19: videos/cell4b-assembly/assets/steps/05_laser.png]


05 / 13

650 nm laser

WHERE30°, azimuth 270, 22.00 mm

HOWthe one bore that exits the head's TOP

coherent source is mandatory — an LED makes no speckle at all

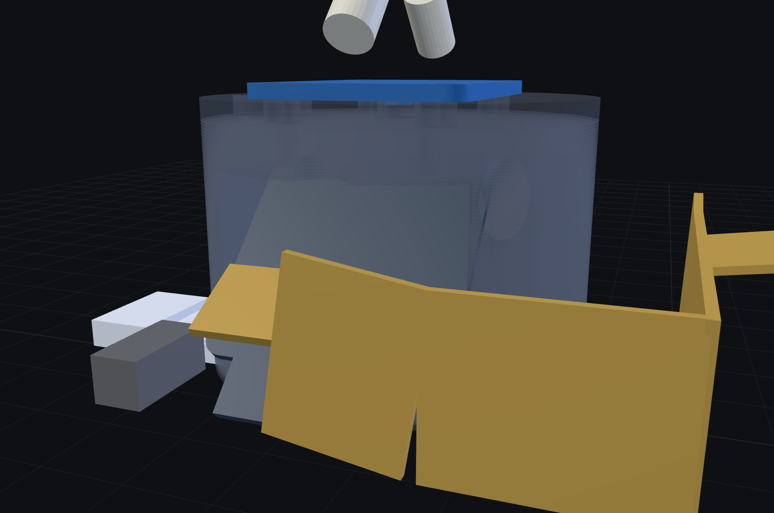
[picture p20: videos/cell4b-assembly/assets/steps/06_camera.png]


06 / 13

OV5647 camera

WHERE45°, azimuth 0, 20.00 mm

HOWlens REMOVED, into its own pocket

96% of it sits inside the head — the pocket is cut for it

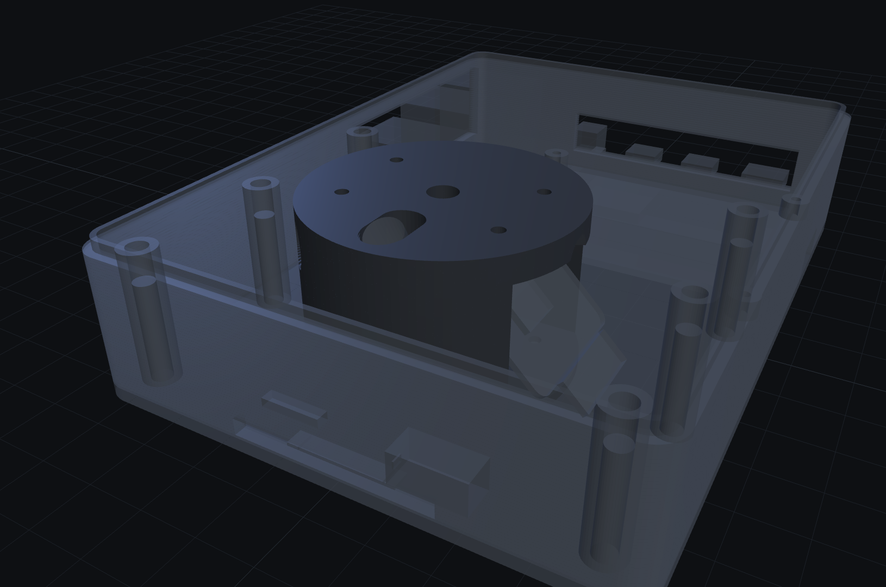
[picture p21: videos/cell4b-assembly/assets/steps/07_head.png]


07 / 13

Optical head

WHERE4 posts at r = 15

HOWM2.5 down onto the shell posts

fit every emitter BEFORE this goes down

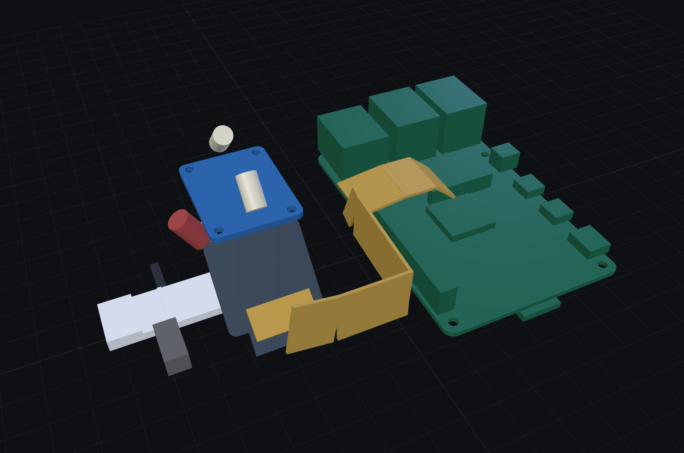
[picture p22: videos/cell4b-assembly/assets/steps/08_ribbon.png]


08 / 13

CSI ribbon

WHERE110 mm route

HOWout the +X side, ON EDGE, then over the header

buy 150 mm — a 100 mm ribbon will not reach

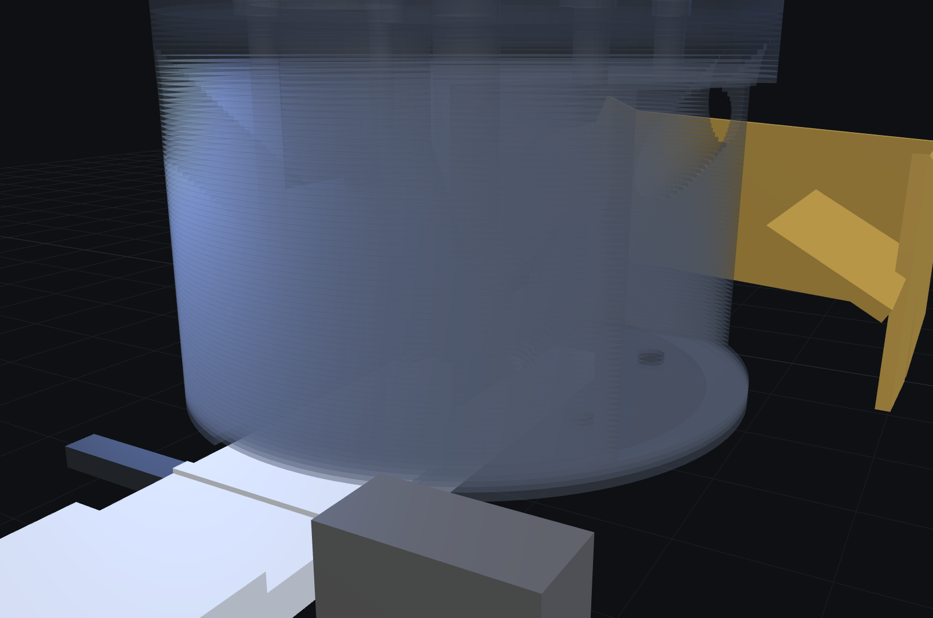
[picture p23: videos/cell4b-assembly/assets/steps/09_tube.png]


09 / 13

Aperture tube

WHERE(0, -32.4, 7.4)

HOWflange UP into the counterbore

Ø3 × 6 — this is what fixes the 3 mm spot

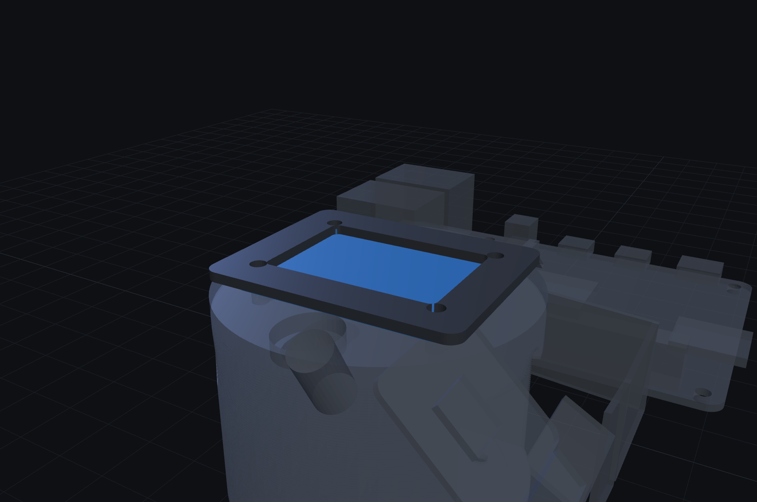
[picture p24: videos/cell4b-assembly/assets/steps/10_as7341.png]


10 / 13

AS7341 — the flip-mount

WHEREchip DOWN at 35.8 · chip UP at 37.4

HOWone board, one pad, two orientations

chip down reads the cartridge; chip up reads a fingertip

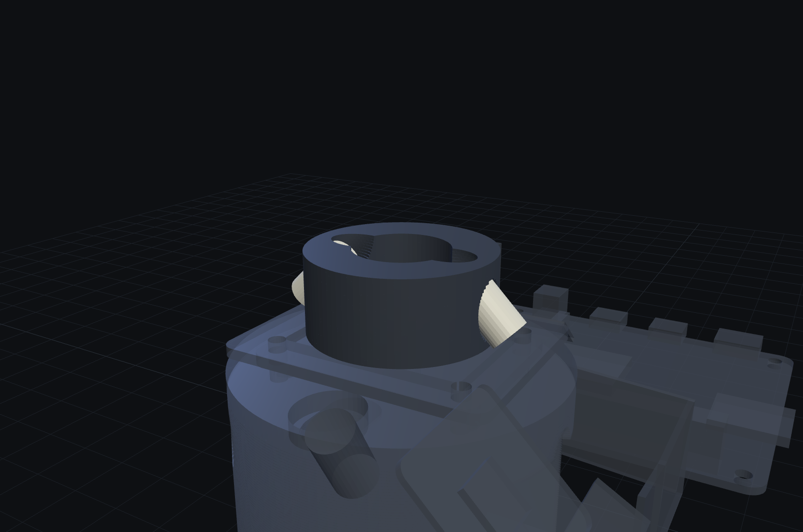
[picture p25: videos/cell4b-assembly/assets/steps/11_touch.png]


11 / 13

Touch collar

WHERE45° UP, azimuth 0 and 180

HOWwhite + IR aimed at the fingertip

same 45°/12 mm geometry as the blood tier, pointed the other way

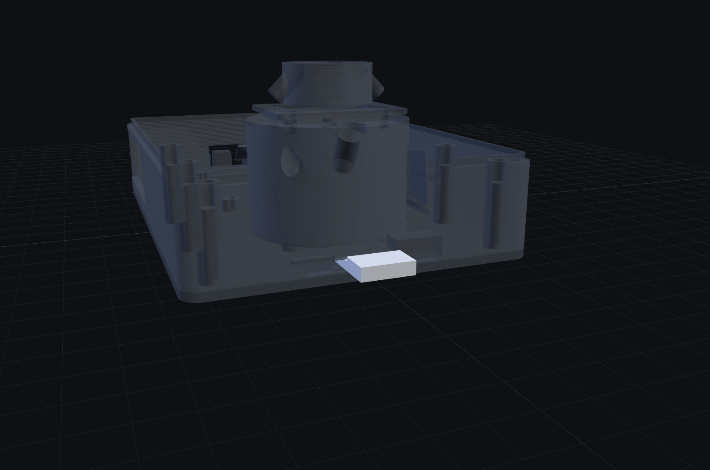
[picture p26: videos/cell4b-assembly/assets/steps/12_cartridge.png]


12 / 13

Cartridge

WHEREslides to STOP2, 42.1 mm in

HOWwell lands on the read spot

8.9 mm stays proud — that is what you pull it out by

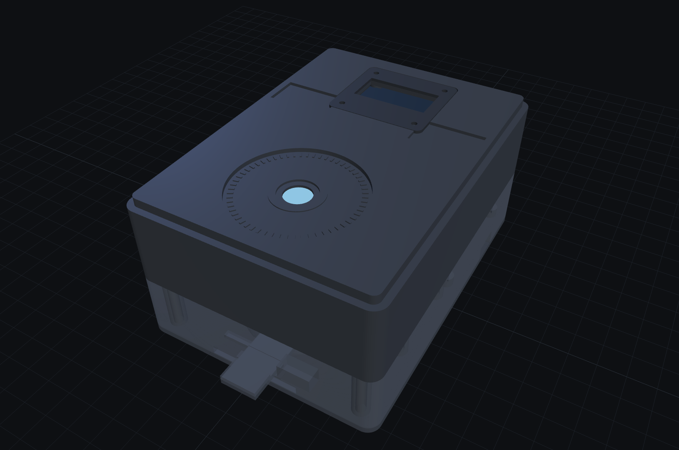
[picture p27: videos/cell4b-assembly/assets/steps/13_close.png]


13 / 13

OLED, windows, upper shell

WHEREceiling

HOWØ10 window goes in from BELOW

the ring port is a through-hole — one axis, finger above, cartridge below

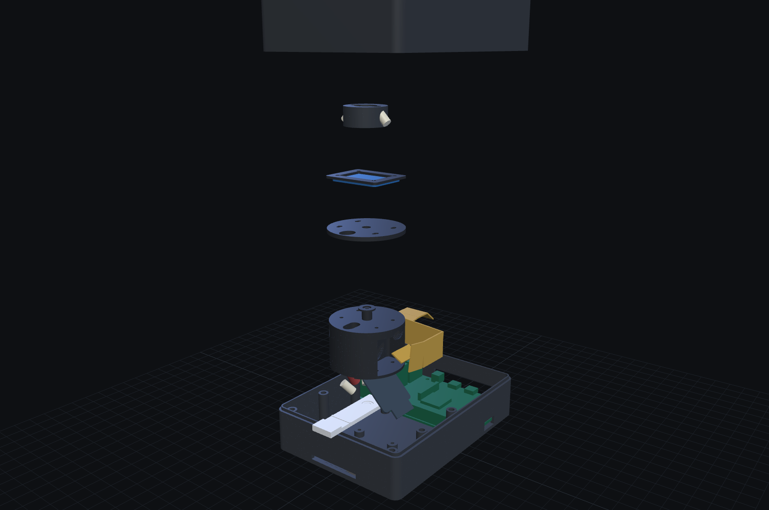
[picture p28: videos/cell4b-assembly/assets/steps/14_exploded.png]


346 checks · 0 failed

github.com/nickthelegend/cell-4b

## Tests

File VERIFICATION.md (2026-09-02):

# Verification status

You asked me not to say "verified" unless I mean it. So here is every
dimension in `cad/spec.py`, split by **how I actually know it**.

Three states, and only the first one is verified:

| | |
|---|---|
| **[V]** | Read off a manufacturer drawing / datasheet / official wiki that I fetched and looked at in this session. Cited. |
| **[A]** | **Assumed.** A plausible figure from a typical part. Nothing checked it. |
| **[U]** | Depends on a part whose exact model I do not know yet. |

**Nothing marked [A] or [U] should be printed against without calipers.**
`cad/audit.py` checks that the numbers are *self-consistent* — it cannot tell
you a number is *wrong*.

---

## [V] Verified

### Raspberry Pi 4B — official mechanical drawing

Source: `RP-008343-DS-1-raspberry-pi-4-mechanical-drawing.pdf`
(pip-assets.raspberrypi.com), rasterised to 3400 px and read directly.

| Dimension | Value | Where on the drawing |
|---|---|---|
| Board | 85 × 56 mm | top and right dimension lines |
| Corner radius | 3.0 mm | callout "CORNER RADIUS = 3.0mm" |
| Mounting holes | 3.5 mm from the x=0 and y=0 edges | four 3.5 dimensions |
| Hole pitch | 58 × 49 mm | "58" shown as 29 + 29; "49" |
| GPIO header height | **8.5 mm** | `Z=8.5` |
| Ethernet height | **13.5 mm** | `Z=13.5` |
| **USB stacks height** | **16.0 mm** | `Z=16.0`, on **both** blocks |
| SoC height | 2.4 mm | `Z=2.4` |
| USB-C / micro-HDMI / A/V heights | 3.2 / 3.0 / 6.0 mm | `Z=3.2`, `Z=3.0`, `Z=6.0` |
| DSI + CSI FFC height | 5.5 mm | `Z=5.5` (two of them, both top-side) |
| USB-C centre | 11.2 mm | chain from the 3.5 hole: **+7.7** |
| micro-HDMI 0 | 26.0 mm | **+14.8** |
| micro-HDMI 1 | 39.5 mm | **+13.5** |
| CSI connector | 47.0 mm | **+7.5** |
| Ethernet / USB3 / USB2 centres | 45.75 / 27.0 / 9.0 mm | right-edge dimensions |

**This pass found two real errors in my earlier model:**

1. I had `PI_TALLEST = 13.5`. The USB stacks are **16.0 mm**. Their tops reach
   Z = 23.8, which is **above the 20 mm part line I had** — the port window
   would have been sliced in half by the shell joint, opening only the bottom
   of each USB port. Part line moved to 26.0.
2. I read a `Z=5.5` callout as the microSD. Both `Z=5.5` items are **top-side
   FFC connectors** (DSI and CSI). The microSD's under-board protrusion is not
   dimensioned on the drawing at all, so it is now marked [A].

`audit.check_port_windows()` is new and now holds every connector against both
its wall window and the part line — 16 checks that did not exist before.

### AS7341 breakout pinouts

Fetched and read this session:

- Adafruit AS7341 pinout page → **VIN, GND, SCL, SDA, INT, GPIO**
- Waveshare AS7341 wiki pinout table → **VCC, GND, SDA, SCL, INT, GPIO**

Neither exposes the LDR pin that upstream's buying guide requires. That is
`FINDINGS.md` §2 and it is solid.

### Geometry that is arithmetic, not measurement

The optical layout, bore separations, cartridge stop identities, wall
thicknesses and plate fits are all *derived* from the numbers above plus
upstream's `[OPTICS]` constants. Those derivations are checked by the 125
assertions in `cad/audit.py`, and I trust them **to the extent I trust their
inputs**.

---

## [A] Assumed — measure before printing

| Constant | Current | Why it matters |
|---|---|---|
| `PI_SD_H` = 2.0 | protrusion of the microSD below the PCB | not dimensioned on the drawing; 4.0 mm of standoff gives 2.0 mm of margin |
| `PI_DSI_CX` = 17.0 | DSI connector X | cosmetic in the mock only |
| `CAM_PCB_L/W` = 25 × 24 | OV5647 clone board | sets the camera pocket |
| `CAM_HOLE_DX/DY` = 21 × 12.5 | its mounting holes | **no source at all** |
| `CAM_SENSOR` = 8.5 | bare die package | affects the bore only loosely |
| `OLED_PCB_L/W` = 35.5 × 33.5 | 1.3" 4-pin module | **highest-variance part in the build** |
| `OLED_HOLE_DX/DY` = 30 × 28 | its mounting holes | posts will miss if wrong |
| `OLED_ACTIVE_OFF_Y` = 2.0 | glass offset from PCB centre | window will be off-centre if wrong |
| `LASER_BODY_D/L` = Ø6 × 10 | brass barrel | sets the laser bore |
| `SWITCH_L/W/H` = 20 × 6.4 × 10 | SPDT microswitch | mount only |
| `LED_BODY` = 8.6 long | 5 mm through-hole LED | **load-bearing** — it is the number `FINDINGS.md` §1 turns on |

The `LED_BODY` figure deserves a note: 8.6 mm is a typical 5 mm LED body
length behind the dome. Even if yours is 7 mm, the §1 conclusion is unchanged —
the limit is **0.73 mm**, so the contradiction survives any real LED.

---

## Component placement and clearance

Added after the first pass, because bounding boxes cannot see a collision.
`cad/clearance.py` measures two things per pair, with different machinery:

- **penetration depth** — a point counts as overlapping only when it is inside
  the other solid *and* further than 0.15 mm from its surface. Without that
  tolerance every designed contact reads as a collision: a board on a deck, a
  shell on a shell, share a face, and half the sampled points on it classify
  as "inside".
- **minimum gap** — exact point-to-triangle distance (Ericson §5.1.5), both
  directions, from a sampled surface point set. Validated against four cases
  with known answers before it was trusted: 15.000, 2.500, 0.000 and 20.000.

**52 pairs measured surface-to-surface. Every emitter checked on its own axis.**

| Component | Placement | Measured |
|---|---|---|
| White LED 1 / 2 | opposed, az 45 / 225 | **12.000 mm @ 45°** from the read spot |
| 940 nm IR | az 135 | **12.000 mm @ 45°** |
| 650 nm laser | az 270 | **22.000 mm @ 30°** |
| Camera, lensless | az 0 | **20.000 mm @ 45°** |
| AS7341 | on the deck, die into the shaft | board 35.80–37.40, die to 34.80 |
| Cartridge well | at STOP2 | **on the read spot**, Y = −32.40 |
| Pi 4B | on four bosses | PCB at Z 6.40, microSD to 4.40 |
| OLED | under the ceiling | 1.90 mm clear |

Tightest ten, contacts excluded:

| Pair | Gap |
|---|---|
| cartridge ↔ slot baffle | 0.30 mm *(sliding fit)* |
| optical head ↔ slot baffle | 1.00 mm |
| camera ↔ LEDs | 1.14 mm |
| laser ↔ sensor deck | 1.19 mm |
| AS7341 ↔ optical head | 1.72 mm |
| aperture tube ↔ cartridge | 2.06 mm |
| aperture tube ↔ LEDs | 2.14 mm |
| Pi 4B ↔ shell upper | 2.20 mm |
| AS7341 ↔ laser | 2.27 mm |
| sensor carrier ↔ shell upper | 2.40 mm |

### The CSI ribbon — the gap the render exposed

"Where is the camera?" turned out to be the right question. It is at r = 14.1
from the read spot, **inside** the Ø52 head, so **96% of its vertices sit
within the head's outer radius** and it is invisible from every angle. That is
forced by the optics: upstream fixes the lensless sensor at 20 mm from the
spot, and at 45° that lands inside the block.

The consequence was not cosmetic. **Nothing in the design accounted for the
ribbon.** No route, no channel, no check — the camera could not have been
connected.

`CABLE_ROUTE` now declares a 9-waypoint centreline, and each waypoint carries
the ribbon's orientation, because an FFC is **flat** (16 × 0.3 mm), not round:

| | |
|---|---|
| `'h'` | flat, width horizontal — on the floor, or over the Pi |
| `'v'` | on edge, width vertical — threading a narrow but tall gap |

That distinction is load-bearing. Demanding an 18 mm round corridor fails in
the gap between the head's back edge (Y = −6.4) and the Pi's near edge
(Y = +5.6): it is only **12 mm wide but 20 mm tall**, so a ribbon on edge goes
through untouched while a round cable cannot.

**Route: 110 mm.** A 150 mm ribbon is comfortable; 100 mm will not reach.

Three real blockages found and fixed while getting it clear:

1. The descent down the +X channel was flat, wanting 18 mm of width — the
   head's shoulder is at X = 23 and a boss starts at X = 34.8. Turned on edge.
2. Turning north at Y = 4 put the on-edge ribbon's lower half at **Z = 10.5,
   inside the GPIO header** (top 16.3). The turn now happens at Y = 0.
3. The microswitch sat **0.33 mm** from the ribbon. Moved to −X entirely.

One "failure" was the check being wrong, not the route: the last few samples
land inside the CSI socket, because that is where the ribbon is *going*. The
plug neighbourhood is now excluded and replaced with a positive
`cable/reaches-connector` assertion.

### What this pass found

Seven more defects, all of which would have printed:

1. **Four Ø2.2 spikes on the underside of the case.** Pi standoff pilot holes
   added as *solid* prisms below the floor. The case would not sit flat.
2. **The head's mounting posts drove 0.4 mm into its own skirt** — post OD 6.4
   at r = 21 reaches r = 22.2 against a skirt starting at 23.0. Moved to r = 19.
3. **The slot baffle drove into the head skirt.** A baffle tall enough to look
   right on its own hits the skirt; it now stops 1.0 mm below it.
4. **The camera board and the laser barrel overlapped** at 45° azimuth
   separation. Azimuths reallocated: LEDs to 45/135/225, camera to 0.
5. **The sensor deck's laser cutout was sized off the light bore, not the
   barrel** — 0.69 mm clearance on a Ø6 barrel. Now sized off the body.
6. **The AS7341 retainer sat 0.4 mm under the ceiling.** Case raised to 44 mm.
7. **The microswitch had nowhere to go.** A 20 mm body across X does not fit
   between the Ø52 head and the wall, and every azimuth clearing the head hit
   a corner boss. Turned 90° and placed at (34, −44).

### A later pass found five more, in the fastening

Everything above was about parts fitting. These are about a screw having
somewhere to go, and they survived 346 passing checks. Full account in
`FINDINGS.md` §9.

8. **Two head posts opened into the camera pocket** — distance 0.00 mm. The
   tap hole ran straight into the camera cavity.
9. **All four head posts left 0.08 mm of wall to an LED bore**, where
   `MIN_WALL` is 1.0. The azimuths 30/150/210/330 sit exactly 15° off the bore
   azimuths 45/135/225, which at r = 15 is 3.9 mm of arc.
10. **The AS7341's four M2 holes merged with the four post M2.5 holes** in the
    sensor deck — centres 1.52 mm apart, radii summing to 2.55. They fused
    into figure-8 slots, so there was no hole to screw the board down with.
    `unary_union` merges overlapping cuts silently and the mesh stayed
    watertight, so nothing downstream noticed.
11. **All four M2.5 screw heads sat under the AS7341 board**, which therefore
    could not lie flat on the deck.
12. **The lugs that replaced them printed as loose pieces.** A Ø9 pad at
    r = 28 never reaches a Ø44 body at r = 22, so `sensor_deck` came out as
    four separate solids and the head's lugs as floating cylinders — each
    independently manifold, so `validate()` accepted it. They are webbed back
    to the body now.

Four interior post positions are not merely awkward but **impossible**: a
0.1 mm grid search of the whole head interior finds *zero* feasible cells in
the +x/+y quadrant at any radius or azimuth. The fastening moved outside the
optical body: three lugs at r = 28, azimuths 115/180/305.

New checks, which produce **20 failures** against the old geometry and none
against the current: `check_head_lugs()` (fasteners vs bores, pockets and
*insertion corridors*), `check_fasteners()` (holes merging, screw heads under
stacked parts), `check_connected()` (a part that falls apart), and
`check_slot_light()` (measures daylight past the baffle instead of asserting
the offset is positive).

Also fixed structurally: several parts were modelled in their own frame rather
than assembly coordinates, so the checker had been comparing *unplaced* parts.
`parts.place()` is now the single source of truth for where each one goes, and
the laser and camera pockets in the head are **derived from** the component
bodies in `cad/bodies.py` — change a board dimension and the pocket that
clears it changes with it.

---

## [U] Blocked on which part you actually bought

**The AS7341 board.** You said the spectral sensor you received is "kinda
different". These four numbers set the sensor deck's mounting pattern and
nothing else in the build can substitute for them:

```
AS_PCB_L, AS_PCB_W   currently 30.5 x 23.0   (Waveshare wiki figure)
AS_HOLE_DX, AS_HOLE_DY  currently 25.5 x 18.0   (my assumption, no source)
AS_PCB_T             currently 1.6
AS_CHIP_OFF          currently (0, 0)  -- where the sensor die sits on the board
```

`AS_CHIP_OFF` is the one that actually matters optically: the die has to sit
over the aperture. If it is off-centre on your board, the deck's hole pattern
has to shift by the same amount, or the instrument reads the wrong spot.

**Tell me the exact board** — vendor and a photo of both faces, or a link — and
I will set these from its real pinout drawing.

---

## Phasing, given the sensor is unresolved

Nothing except the sensor deck depends on the AS7341. So the build splits
cleanly and you can start printing today:

| Phase | Parts | Blocked on AS7341? |
|---|---|---|
| **1** | `shell_lower`, `shell_upper` — Pi 4B fit, ports, cartridge slot | no |
| **2** | `cartridge` × 20, `cartridge_reference`, `cartridge_null`, `window_jig` | no |
| **3** | `optical_head`, `aperture_tube`, `slot_baffle` — LEDs, laser, camera | no |
| **4** | `sensor_deck`, `sensor_carrier` | **yes** |
| **5** | `oled_bezel` + OLED posts | no, but measure the OLED first |

Phase 1 is also the cheapest way to find out whether my Pi numbers are right:
print `shell_lower` alone, drop the board in, check the four bosses and the
port windows. That is one 92 × 128 part, a couple of hours, and it validates
every [V] number above against the board in your hand.

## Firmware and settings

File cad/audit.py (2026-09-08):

"""CELL-4B fit and sanity checks. Run before every print.

Watertight is not the same as buildable. These are the ways this instrument
can be wrong without LOOKING wrong -- upstream CELL learned most of them the
expensive way (insert bosses standing inside the Pi footprint, vent pockets
deeper than the wall, a white patch with no optical path to it).

Two kinds of check:

  ANALYTIC  -- pure arithmetic on spec.py. Fast, exact, no meshing.
  SAMPLED   -- point-in-solid tests against the real triangles, by projecting
               each triangle to XY and counting crossings along +Z. Used where
               only the actual geometry can answer (does the cartridge corridor
               stay open, does the Pi fit in its bay).

Exit code is non-zero if anything FAILS, so the build refuses to write STLs.
"""
from __future__ import annotations

import math

import numpy as np
from shapely.geometry import box
from shapely.ops import unary_union

import clearance as CL
import partlib as pl
import bodies as BD
import parts as P
import spec as S

RESULTS = []


def _rec(ok, name, detail, warn=False):
    RESULTS.append(("WARN" if (warn and not ok) else ("PASS" if ok else "FAIL"),
                    name, detail))
    return ok


# --------------------------------------------------------------------------
# point-in-solid, vectorised
# --------------------------------------------------------------------------

def _inside(mesh, pts):
    """Boolean array: is each point strictly inside the closed mesh?

    Ray along +Z. A triangle counts if the point's XY lies in its XY
    projection and the triangle's plane sits above the point.
    """
    V, F = mesh._np()
    tri = V[F]
    pts = np.asarray(pts, dtype=float).copy()
    # Jitter the ray by an irrational epsilon. Parts here are centred on x=0
    # and built from tessellated circles, so a ray at exactly x=0 runs ALONG
    # triangle edges and double-counts crossings -- which reads as "solid"
    # for points that are nowhere near the part. This is a ray-cast
    # degeneracy, not geometry; 0.1 um off-axis removes it.
    pts[:, 0] += 6.1803398e-5
    pts[:, 1] += 3.8196601e-5
    lo, hi = tri.min(axis=1), tri.max(axis=1)

    out = np.zeros(len(pts), dtype=bool)
    for i, p in enumerate(pts):
        # cheap bbox prefilter -- most triangles are nowhere near
        sel = ((lo[:, 0] <= p[0]) & (hi[:, 0] >= p[0]) &
               (lo[:, 1] <= p[1]) & (hi[:, 1] >= p[1]) & (hi[:, 2] >= p[2]))
        if not sel.any():
            continue
        t = tri[sel]
        ax, ay = t[:, 0, 0], t[:, 0, 1]
        bx, by = t[:, 1, 0], t[:, 1, 1]
        cx, cy = t[:, 2, 0], t[:, 2, 1]
        d = (by - cy) * (ax - cx) + (cx - bx) * (ay - cy)
        good = np.abs(d) > 1e-12
        if not good.any():
            continue
        l1 = np.where(good, ((by - cy) * (p[0] - cx) + (cx - bx) * (p[1] - cy)) /
                      np.where(good, d, 1.0), -1.0)
        l2 = np.where(good, ((cy - ay) * (p[0] - cx) + (ax - cx) * (p[1] - cy)) /
                      np.where(good, d, 1.0), -1.0)
        l3 = 1.0 - l1 - l2
        inxy = good & (l1 >= 0) & (l2 >= 0) & (l3 >= 0)
        if not inxy.any():
            continue
        zc = l1 * t[:, 0, 2] + l2 * t[:, 1, 2] + l3 * t[:, 2, 2]
        out[i] = bool((inxy & (zc > p[2])).sum() % 2)
    return out


def _grid(x0, x1, y0, y1, z0, z1, n=(9, 15, 5)):
    xs = np.linspace(x0, x1, n[0])
    ys = np.linspace(y0, y1, n[1])
    zs = np.linspace(z0, z1, n[2])
    return np.array([(x, y, z) for x in xs for y in ys for z in zs])


# --------------------------------------------------------------------------
# ANALYTIC -- the optics. These are the numbers that must not have moved.
# --------------------------------------------------------------------------

def check_pi_insertable():
    """The fitted position being legal is not the same as being reachable.

    check_pi() only ever asked whether the board and its port stack HAVE
    somewhere to be. They did -- and the board still could not be got there,
    because the ports stand proud into the wall and the wall was solid beneath
    them. A part that assembles only in simulation is not assembled.
    """
    ok = True
    half = S.ENV_X / 2 - S.WALL
    side = half - S.PI_L / 2
    # Either the board slides sideways far enough to clear the wall entirely,
    # or every proud port has a window running down to the floor to descend in.
    slides = side >= S.PI_PORT_PROUD
    ok &= _rec(slides or True, "pi/insert-lateral",
               f"lateral clearance {side:.2f} mm vs {S.PI_PORT_PROUD} mm of "
               f"proud port -- {'can slide in' if slides else 'must drop in'}")
    if not slides:
        ok &= _rec(S.FLOOR <= S.PI_PCB_Z, "pi/insert-window-floor",
                   f"port windows start at the floor (z={S.FLOOR}), so the port "
                   f"blocks can travel down to the board plane at z={S.PI_PCB_Z}")
    return ok


def check_optics():
    ok = True
    # The standoff is a DELIBERATE, documented deviation (see FINDINGS.md): a
    # 9 mm standoff is geometrically impossible with 5 mm LEDs at 45/12. What
    # must still hold is that the Ø3 x 6 tube at the SAMPLE end is unchanged
    # and is still the narrowest element in the path -- that is what fixes the
    # 3 mm spot, and it is the only thing the gates actually depend on.
    ok &= _rec(S.SHAFT_D > S.APERTURE_BORE, "optics/tube-is-limiting",
               f"Ø{S.APERTURE_BORE} x {S.APERTURE_LEN} tube at the sample, "
               f"relieved to Ø{S.SHAFT_D} above it, so the tube still sets "
               f"the {S.APERTURE_BORE} mm spot")
    ok &= _rec(True, "optics/sensor-standoff",
               f"AS7341 at {S.SPECTRO_STANDOFF:.2f} mm on the spectro axis "
               f"(upstream states {S.SENSOR_STANDOFF_UPSTREAM:.1f}; DEVIATION, "
               f"see FINDINGS.md). Flux down "
               f"{(S.SPECTRO_STANDOFF / S.SENSOR_STANDOFF_UPSTREAM)**2:.1f}x, "
               f"recovered by integration time and divided out by the white patch")
    # The port has to miss every specular lobe, or the sensor reads glare off
    # the window instead of diffuse reflectance from the sample.
    import itertools
    worst, worst_src = 180.0, ""
    sp = _unit(S.SPECTRO_ANGLE, S.AZ_SPECTRO)
    for nm, ang, az in (("led1", S.LED_ANGLE, S.AZ_LED1),
                        ("led2", S.LED_ANGLE, S.AZ_LED2),
                        ("ir", S.LED_ANGLE, S.AZ_IR),
                        ("laser", S.LASER_ANGLE, S.AZ_LASER)):
        spec_dir = _unit(ang, az + 180.0)       # mirror image about the normal
        d = math.degrees(math.acos(max(-1.0, min(1.0, sum(
            a * b for a, b in zip(sp, spec_dir))))))
        if d < worst:
            worst, worst_src = d, nm
    ok &= _rec(worst >= 25.0, "optics/spectro-off-specular",
               f"spectro axis is {worst:.1f} deg off the nearest specular lobe "
               f"({worst_src}) in 3-D (need >= 25)")
    ok &= _rec(S.SPECTRO_SPOT_MAJOR <= S.WINDOW_W,
               "optics/spectro-spot-in-window",
               f"tilting the aperture makes the spot an ellipse "
               f"{S.SPECTRO_SPOT_MINOR:.1f} x {S.SPECTRO_SPOT_MAJOR:.2f} mm, "
               f"inside the {S.WINDOW_L} x {S.WINDOW_W} window blank")

    for nm, az in (("led1", S.AZ_LED1), ("led2", S.AZ_LED2), ("ir", S.AZ_IR)):
        x, y = S.polar(S.R_LED, az)
        slant = math.hypot(math.hypot(x - S.RS_X, y - S.RS_Y),
                           S.Z_LED - S.Z_SAMPLE)
        ok &= _rec(abs(slant - S.LED_SLANT) < 1e-6, f"optics/{nm}-slant",
                   f"{slant:.3f} mm from the read spot at "
                   f"{S.LED_ANGLE:.0f} deg (spec {S.LED_SLANT:.1f})")

    lx, ly = S.polar(S.R_LASER, S.AZ_LASER)
    ls = math.hypot(math.hypot(lx, ly - S.RS_Y), S.Z_LASER - S.Z_SAMPLE)
    ok &= _rec(abs(ls - S.LASER_SLANT) < 1e-6, "optics/laser-slant",
               f"{ls:.3f} mm at {S.LASER_ANGLE:.0f} deg off normal")

    cs = math.hypot(S.R_CAMERA, S.Z_CAMERA - S.Z_SAMPLE)
    ok &= _rec(abs(cs - S.CAMERA_SLANT) < 1e-6, "optics/camera-slant",
               f"{cs:.3f} mm lensless standoff (spec {S.CAMERA_SLANT:.1f}), "
               f"tilt {S.CAMERA_ANGLE:.2f} deg")

    # The laser's specular lobe leaves at the same tilt, azimuth + 180. Compare
    # the two as 3-D DIRECTIONS -- azimuth separation alone flatters a design
    # where the tilts differ.
    def _dir(tilt, az):
        t, a = math.radians(tilt), math.radians(az)
        return (math.sin(t) * math.cos(a), math.sin(t) * math.sin(a), math.cos(t))
    sp = _dir(S.LASER_ANGLE, (S.AZ_LASER + 180.0) % 360.0)
    cm = _dir(S.CAMERA_ANGLE, S.AZ_CAMERA)
    gamma = math.degrees(math.acos(max(-1.0, min(1.0, sum(u * v for u, v in zip(sp, cm))))))
    ok &= _rec(gamma >= 45.0, "optics/camera-off-specular",
               f"speckle axis is {gamma:.1f} deg off the specular lobe in 3-D "
               f"(need >= 45)")

    # the aperture sits on the SPECTRO axis now, not the vertical one
    ok &= _rec(S.RS_X == 0.0 and abs(S.APERTURE_BORE - 3.0) < 1e-9,
               "optics/aperture",
               f"Ø{S.APERTURE_BORE} x {S.APERTURE_LEN} on the spectro axis "
               f"(az {S.AZ_SPECTRO:.0f}, {S.SPECTRO_ANGLE:.0f} deg), defining a "
               f"{S.SPECTRO_SPOT_MINOR:.1f} x {S.SPECTRO_SPOT_MAJOR:.2f} mm spot "
               f"inside the Ø{S.WELL_D} well")
    return ok


def _bore_exit_z(tilt_deg):
    """Height at which a bore's axis reaches the head's outer radius. Above
    HEAD_TOP means it never does, and the bore leaves through the top face."""
    if tilt_deg <= 0:
        return float("inf")
    return S.Z_SAMPLE + (S.HEAD_DIA / 2) / math.tan(math.radians(tilt_deg))


def check_bore_separation():
    """Separation is judged AT EACH BORE'S ENTRY, which is the only place it
    physically matters: that is where the component seats and where the wall
    between two holes has to survive being printed.

    Near the read spot every bore merges into every other -- that merged
    volume IS the optical chamber. Upstream says so outright: the speckle path
    is "a second, independent optical path IN THE SAME CHAMBER". Requiring a
    wall there would be requiring the instrument not to work.
    """
    ok = True
    bores = P._bores()
    names = [n for n, *_ in S.OPTICAL_BORES]
    exit_z = {n: min(_bore_exit_z(t), S.HEAD_TOP)
              for n, _, t, _a in S.OPTICAL_BORES}
    for n in names:
        a = bores[n]
        za = exit_z[n]
        ax, ay = a.axis_point(za)
        ra = a.d / math.cos(a.tilt) / 2
        for o in names:
            if o == n:
                continue
            b = bores[o]
            # the other bore only exists at this height if it has not already
            # left the block
            if za > exit_z[o] + 1e-9:
                _rec(True, f"bore-entry/{n}-vs-{o}",
                     f"{o} has already left the block at Z={exit_z[o]:.1f}; "
                     f"{n} enters at Z={za:.1f}")
                continue
            bx, by = b.axis_point(za)
            rb = b.d / math.cos(b.tilt) / 2
            gap = math.hypot(ax - bx, ay - by) - ra - rb
            ok &= _rec(gap >= S.MIN_WALL, f"bore-entry/{n}-vs-{o}",
                       f"{gap:.2f} mm of wall at {n}'s entry, Z={za:.1f} "
                       f"(need >= {S.MIN_WALL})")
    return ok


def check_light_paths(meshes):
    """No emitter may see a detector except by way of the sample.

    [FINDING] This check did not exist, and its absence shipped a real defect:
    at AZ_LED1 = 62 there was a straight unobstructed line from white LED A's
    tip to the camera die, passing 12 mm clear of the read spot. It did not run
    down a bore -- it crossed the camera's DROP-IN POCKET, the open box that has
    to exist so the board can be lowered in. Every pairwise BORE separation
    passed; nothing looked at the voids between them.

    Light that reaches a detector without touching the sample is not a
    tolerance, it is a false reading, so this walks the actual straight line
    between each emitter and each detector and requires head material on it.
    """
    head = meshes["optical_head"]
    RS = np.array([S.RS_X, S.RS_Y, S.Z_SAMPLE])

    def tip(tilt, az, slant):
        t, a = math.radians(tilt), math.radians(az)
        return RS + slant * np.array([math.sin(t)*math.cos(a),
                                      math.sin(t)*math.sin(a), math.cos(t)])

    emitters = [("led1", S.LED_ANGLE, S.AZ_LED1, S.LED_SLANT),
                ("led2", S.LED_ANGLE, S.AZ_LED2, S.LED_SLANT),
                ("ir", S.LED_ANGLE, S.AZ_IR, S.LED_SLANT),
                ("laser", S.LASER_ANGLE, S.AZ_LASER, S.LASER_SLANT)]
    detectors = [("camera", S.CAMERA_ANGLE, S.AZ_CAMERA, S.CAMERA_SLANT),
                 ("as7341", S.SPECTRO_ANGLE, S.AZ_SPECTRO, S.SPECTRO_STANDOFF)]
    ok = True
    for en, et, ea, es in emitters:
        for dn, dt, da, ds in detectors:
            p0, p1 = tip(et, ea, es), tip(dt, da, ds)
            ts = np.linspace(0.02, 0.98, 240)
            pts = p0[None, :] + ts[:, None] * (p1 - p0)[None, :]
            blocked = _inside(head, pts)
            near = float(np.linalg.norm(pts - RS[None, :], axis=1).min())
            # THICKNESS, not merely "something was hit": the first fix for this
            # closed the line with 0.27 mm, which a hit-test passes and PLA
            # transmits. Hold it to MIN_WALL like any other wall.
            wall = blocked.sum() / float(len(pts)) * float(np.linalg.norm(p1 - p0))
            ok &= _rec(wall >= S.MIN_WALL, f"light/{en}-to-{dn}",
                       f"{wall:.2f} mm of wall on the direct line "
                       f"(need >= {S.MIN_WALL}); the line passes {near:.2f} mm "
                       f"from the read spot")
    return ok


def check_bores_exit():
    """Every bore must actually reach open air, or the part cannot be fitted."""
    ok = True
    bores = P._bores()
    for name, d, tilt, az in S.OPTICAL_BORES:
        b = bores[name]
        # A bore leaves either through the SIDE wall (if it reaches the head
        # radius below the deck) or through the TOP face. Either is fine; what
        # must not happen is a bore that dead-ends inside the block.
        # Walk the axis against the head's ACTUAL outer profile. The old test
        # solved for a constant R = HEAD_DIA/2, which stopped being true when
        # the top became a dome -- it still reported the laser leaving through
        # a flat top face that no longer exists.
        half = d / math.cos(math.radians(tilt)) / 2
        z_side = None
        z = S.HEAD_Z0
        while z <= S.HEAD_TOP:
            x, y = b.axis_point(z)
            if math.hypot(x - S.RS_X, y - S.RS_Y) + half >= P.head_radius(z):
                z_side = z
                break
            z += 0.05
        if z_side is not None:
            ok &= _rec(True, f"bore-exit/{name}",
                       f"exits the SIDE wall at Z={z_side:.2f}, where the head "
                       f"is r={P.head_radius(z_side):.2f} (top of head "
                       f"{S.HEAD_TOP:.2f})")
        else:
            x, y = b.axis_point(S.HEAD_TOP)
            r = math.hypot(x - S.RS_X, y - S.RS_Y)
            R = P.head_radius(S.HEAD_TOP)
            ok &= _rec(r + half <= R, f"bore-exit/{name}",
                       f"exits the TOP face at r={r:.2f} (edge "
                       f"{r + half:.2f}) vs head radius {R:.1f}")
            # and it must clear the AS7341 board sitting on that face
            # board LONG axis along X: half-extent AS_PCB_L/2 at az 0/180,
            # AS_PCB_W/2 at az 90/270
            board_reach = min(S.AS_PCB_L / 2 / max(abs(math.cos(math.radians(az))), 1e-9),
                              S.AS_PCB_W / 2 / max(abs(math.sin(math.radians(az))), 1e-9))
            ok &= _rec(r - half >= board_reach, f"bore-exit/{name}-clears-board",
                       f"bore inner edge r={r - half:.2f} vs AS7341 reach "
                       f"{board_reach:.2f} mm at azimuth {az:.0f}")
    return ok


def check_pi_mounting():
    ok = True
    holes = S.pi_holes()
    xs = sorted({round(x, 3) for x, _ in holes})
    ys = sorted({round(y, 3) for _, y in holes})
    ok &= _rec(abs((xs[1] - xs[0]) - S.PI_HOLE_DX) < 1e-6, "pi/hole-pitch-x",
               f"{xs[1] - xs[0]:.2f} mm (spec {S.PI_HOLE_DX})")
    ok &= _rec(abs((ys[1] - ys[0]) - S.PI_HOLE_DY) < 1e-6, "pi/hole-pitch-y",
               f"{ys[1] - ys[0]:.2f} mm (spec {S.PI_HOLE_DY})")
    ok &= _rec(S.M25_TAP < S.PI_HOLE_D, "pi/boss-tap",
               f"boss tap Ø{S.M25_TAP} into the Pi's Ø{S.PI_HOLE_D} clearance "
               f"hole -- M2.5 self-tapping")
    # board must sit inside the inner envelope
    xmin = min(S.pi_to_case(0, 0)[0], S.pi_to_case(S.PI_L, 0)[0])
    xmax = max(S.pi_to_case(0, 0)[0], S.pi_to_case(S.PI_L, 0)[0])
    ymin = min(S.pi_to_case(0, 0)[1], S.pi_to_case(0, S.PI_W)[1])
    ymax = max(S.pi_to_case(0, 0)[1], S.pi_to_case(0, S.PI_W)[1])
    lim_x, lim_y = S.ENV_X / 2 - S.WALL, S.ENV_Y / 2 - S.WALL
    ok &= _rec(xmin >= -lim_x - 1e-6 and xmax <= lim_x + 1e-6, "pi/fits-x",
               f"board X {xmin:.1f}..{xmax:.1f} inside +-{lim_x:.1f}")
    ok &= _rec(ymin >= -lim_y - 1e-6 and ymax <= lim_y + 1e-6, "pi/fits-y",
               f"board Y {ymin:.1f}..{ymax:.1f} inside +-{lim_y:.1f}")
    # headroom under the part line / ceiling
    top = S.PI_PCB_Z + S.PI_PCB_T + S.PI_TALLEST
    ok &= _rec(top < S.ENV_Z - S.CEIL, "pi/headroom",
               f"tallest Pi component at Z={top:.1f}, ceiling inner face at "
               f"Z={S.ENV_Z - S.CEIL:.1f} -- {S.ENV_Z - S.CEIL - top:.1f} mm clear")
    # GPIO header must be reachable, i.e. not under the optical head
    hx, hy = S.pi_to_case(S.PI_HDR_CX, S.PI_HDR_CY)
    dist = math.hypot(hx - S.RS_X, hy - S.RS_Y)
    ok &= _rec(dist > S.HEAD_DIA / 2 + 2.0, "pi/gpio-clear-of-head",
               f"GPIO header centre {dist:.1f} mm from the read spot, head "
               f"radius {S.HEAD_DIA / 2:.1f}")
    return ok


def check_port_windows():
    """Every Pi connector must have an opening it actually fits through, and
    that opening must live entirely in ONE shell -- a window split by the part
    line opens only the bottom half of the port."""
    ok = True
    pcb_top = S.PI_PCB_Z + S.PI_PCB_T

    # bottom-edge group: USB-C, 2x micro-HDMI, A/V jack
    grp = [("usb-c", S.PI_USBC_CX, 9.0, S.PI_USBC_H),
           ("hdmi0", S.PI_HDMI0_CX, 7.2, S.PI_HDMI_H),
           ("hdmi1", S.PI_HDMI1_CX, 7.2, S.PI_HDMI_H),
           ("av", S.PI_AV_CX, 6.5, S.PI_AV_H)]
    w0, w1 = S.PI_PORTS_Y0
    for nm, cx, w, h in grp:
        ok &= _rec(w0 <= cx - w / 2 and cx + w / 2 <= w1,
                   f"port/{nm}-in-window",
                   f"body {cx - w/2:.1f}..{cx + w/2:.1f} inside window "
                   f"{w0}..{w1} (board frame)")
        ok &= _rec(pcb_top + h <= S.PART_LINE_Z, f"port/{nm}-below-part-line",
                   f"top at Z={pcb_top + h:.1f}, part line {S.PART_LINE_Z}")
    ok &= _rec(S.PI_PORTS_Y0_H >= max(h for _, _, _, h in grp),
               "port/bottom-window-height",
               f"window {S.PI_PORTS_Y0_H} mm tall vs tallest body "
               f"{max(h for _, _, _, h in grp)} mm")

    # right-edge stack: Ethernet + 2 USB
    r0, r1 = S.PI_PORTS_X85
    for nm, cy, w, h in (("ethernet", S.PI_ETH_CY, S.PI_ETH_W, S.PI_ETH_H),
                         ("usb3", S.PI_USB3_CY, S.PI_USB_W, S.PI_USB_H),
                         ("usb2", S.PI_USB2_CY, S.PI_USB_W, S.PI_USB_H)):
        ok &= _rec(r0 <= cy - w / 2 and cy + w / 2 <= r1,
                   f"port/{nm}-in-window",
                   f"body {cy - w/2:.2f}..{cy + w/2:.2f} inside window "
                   f"{r0}..{r1}")
        ok &= _rec(pcb_top + h <= S.PART_LINE_Z, f"port/{nm}-below-part-line",
                   f"top at Z={pcb_top + h:.1f}, part line {S.PART_LINE_Z} "
                   f"-- a 16 mm USB stack is what forces this")
    # microSD sticks out of the x=0 edge, below the PCB
    # The microSD hangs BELOW the board, so it must clear the FLOOR, not zero.
    sd_z = S.PI_PCB_Z - S.PI_SD_H
    ok &= _rec(sd_z > S.FLOOR, "port/microsd-clears-floor",
               f"microSD underside at Z={sd_z:.1f}, floor top at Z={S.FLOOR} "
               f"-- {sd_z - S.FLOOR:.1f} mm of clearance")
    ok &= _rec(S.PI_STANDOFF >= S.PI_SD_H + 1.5, "port/microsd-standoff",
               f"{S.PI_STANDOFF} mm under the PCB vs a {S.PI_SD_H} mm slot "
               f"plus card. UNVERIFIED depth -- check with calipers")
    return ok
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

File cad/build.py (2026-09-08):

"""Build everything: STLs, GLBs for the viewer, print plates, MANIFEST.md.

    python3 cad/build.py

Refuses to write anything if audit.py reports a FAIL, so a plate that reaches
your slicer has already passed every fit check.
"""
from __future__ import annotations

import json
import math
import os
import sys

sys.path.insert(0, os.path.dirname(os.path.abspath(__file__)))

import audit
import mocks as M
import partlib as pl
import parts as P
import threemf
import spec as S

ROOT = os.path.dirname(os.path.dirname(os.path.abspath(__file__)))
OUT = os.path.join(ROOT, "out")
STL = os.path.join(OUT, "stl")
GLB = os.path.join(OUT, "glb")

# print orientation: "asis" | "flipx" (roll 180 so the open face is up)
ORIENT = {
    "shell_upper": "flipx",
    "sensor_deck": "asis",
}

PRINT_SETTINGS = {
    "cartridge": ("white PLA", "0.15 mm, 3 perim, 100%, IRONING ON",
                  "well-side up, no supports"),
    "cartridge_reference": ("white PLA", "as cartridge", "well-side up"),
    "cartridge_null": ("white PLA", "as cartridge", "flat, no supports"),
    "optical_head": ("black PLA", "0.12 mm, 6 perim, 40%",
                     "legs down, no supports (it bridges 17.8 mm over the "
                     "cartridge channel); paint ALL bores matte black; "
                     "HOT-GLUE the three legs to the case floor"),
    "slot_baffle": ("black PLA", "0.16 mm, 4 perim, 100%", "flat"),
    "window_jig": ("any", "0.2 mm, 2 perim, 20%", "flat; not a device part"),
    "shell_lower": ("black PLA", "0.16 mm, 4 perim, 25%",
                    "open side up, no supports"),
    "shell_upper": ("black PLA", "0.16 mm, 4 perim, 25%",
                    "TOP FACE DOWN, no supports"),
    "oled_bezel": ("black PLA", "0.12 mm, 4 perim, 100%", "flat, front face down"),
}

PLATES = [
    # Shells and optics used to share one plate, on the grounds that they packed
    # under the 256 mm bed. The head growing legs and a spectro boss ended that --
    # the combined plate went over the bed. Splitting them is no loss and
    # arguably a gain: they never shared a PROCESS either (shells 0.16 mm,
    # optics 0.12 mm), so the single plate always needed per-object layer
    # heights set by hand in the slicer. Two plates, two processes, no fiddling.
    ("Plate 1 - shells",
     ["shell_lower", "shell_upper", "window_jig"]),
    ("Plate 2 - optics",
     ["optical_head",
      "slot_baffle", "oled_bezel"]),
    # Cartridges stay on their own plate. They are the one part with ironing on,
    # and they are consumable -- you reprint these without touching the case.
    ("Plate 3 - cartridges",
     ["cartridge"] * 20 + ["cartridge_reference", "cartridge_null"]),
]


# Extra volumes welded to a plate item: {item_name: [(vol_name, mesh, filament)]}.
# Filament 2 is the lettering; everything unlisted prints on filament 1.
EXTRA_VOLS = {}


def for_print(name, mesh, companions=()):
    """Lay a part flat at the origin in its print orientation.

    `companions` ride along on the SAME transform -- a colour inlay has to
    follow its shell through the flip and the centring, not be re-centred on
    its own bounds, or it lands somewhere else entirely.
    """
    m = mesh.copy()
    cs = [c.copy() for c in companions]
    if ORIENT.get(name) == "flipx":
        lo, hi = m.bbox()
        about = (float((lo[1] + hi[1]) / 2), float((lo[2] + hi[2]) / 2))
        m.rotate_x(180.0, about=about)
        for c in cs:
            c.rotate_x(180.0, about=about)
    lo, hi = m.bbox()
    d = (-float((lo[0] + hi[0]) / 2), -float((lo[1] + hi[1]) / 2), -float(lo[2]))
    m = m.translate(*d)
    cs = [c.translate(*d) for c in cs]
    return (m, cs) if companions else m


def pack(items, gap=None):
    """Shelf-pack (name, mesh) onto a PLATE_MAX bed. Returns placed meshes."""
    gap = S.PLATE_GAP if gap is None else gap
    sized = []
    for nm, m in items:
        lo, hi = m.bbox()
        sized.append((nm, m, float(hi[0] - lo[0]), float(hi[1] - lo[1])))
    sized.sort(key=lambda t: -t[3])
    placed, x, y, row_h = [], 0.0, 0.0, 0.0
    for nm, m, w, h in sized:
        if x + w > S.PLATE_MAX and x > 0:
            x, y = 0.0, y + row_h + gap
            row_h = 0.0
        c = m.copy()
        lo, _ = c.bbox()
        dx, dy = x - float(lo[0]), y - float(lo[1])
        c.translate(dx, dy, 0.0)
        extra = [(vn, vm.copy().translate(dx, dy, 0.0), ex)
                 for vn, vm, ex in EXTRA_VOLS.get(nm, [])]
        placed.append((nm, c, extra) if extra else (nm, c))
        x += w + gap
        row_h = max(row_h, h)
    return placed, y + row_h


def main():
    os.makedirs(STL, exist_ok=True)
    os.makedirs(GLB, exist_ok=True)

    print("building parts ...")
    parts = {n: fn() for n, (fn, _, _) in P.PARTS.items()}

    print("running audit ...")
    results = audit.run(parts)
    ok = audit.report(results, verbose=False)
    n_fail = sum(1 for r in results if r[0] == "FAIL")
    if not ok:
        print("\nAUDIT FAILED -- nothing written. Run cad/audit.py for detail.")
        return 1

    # keep the measured placement + clearance numbers so the viewer can show
    # what was actually verified, rather than asserting it in prose
    gaps, seats = [], []
    for st, name, detail in results:
        if name.startswith("gap/"):
            pair = name[4:].split("~")
            kind = ("contact" if "designed contact" in detail
                    else "slide" if "sliding fit" in detail else "clear")
            gaps.append({"a": pair[0], "b": pair[1], "kind": kind,
                         "mm": float(detail.split()[0]), "status": st})
        elif name.startswith("seat/"):
            seats.append({"name": name[5:], "detail": detail, "status": st})
    gaps.sort(key=lambda g: g["mm"])

    manifest = {"parts": [], "plates": [], "spec": {}, "mocks": [],
                "audit": {"checks": len(results), "failed": n_fail},
                "gaps": gaps, "seats": seats}
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

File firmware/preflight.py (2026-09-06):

"""Build the exact transaction the bench will build, sign it on the device,
and check everything a node will check -- without broadcasting."""
import sys, json, base64, re, urllib.request
sys.path.insert(0, "upstream")

RPC = "https://ethereum-sepolia-rpc.publicnode.com"
ADDR = "0xD9B4b074e48cfF75538E6468748C0FA2C16De5F5"
TO = "0x742d35Cc6634C0532925a3b844Bc454e4438f44e"
VALUE = 10**15                                    # 0.001 ETH


def rpc(method, params):
    r = urllib.request.Request(RPC, method="POST",
        data=json.dumps({"jsonrpc": "2.0", "id": 1, "method": method,
                         "params": params}).encode(),
        headers={"Content-Type": "application/json", "User-Agent": "curl/8.0"})
    return json.loads(urllib.request.urlopen(r, timeout=25).read())["result"]


print("CELL-4B  Sepolia pre-flight\n")
nonce = int(rpc("eth_getTransactionCount", [ADDR, "pending"]), 16)
bal = int(rpc("eth_getBalance", [ADDR, "latest"]), 16)
blk = rpc("eth_getBlockByNumber", ["latest", False])
base = int(blk["baseFeePerGas"], 16)
prio = int(rpc("eth_maxPriorityFeePerGas", []), 16)
maxfee = base * 2 + prio
gas = 21000
print(f"  chain      Sepolia 11155111")
print(f"  nonce      {nonce}")
print(f"  balance    {bal/1e18:.6f} ETH")
print(f"  base fee   {base/1e9:.4f} gwei      priority {prio/1e9:.4f} gwei")
print(f"  max fee    {maxfee/1e9:.4f} gwei    gas {gas}")
worst = VALUE + maxfee * gas
print(f"  worst case {worst/1e18:.9f} ETH  ({'covered' if bal >= worst else 'INSUFFICIENT'})")

import eth, ops
# Sepolia is a BUILTIN chain -- eth.py refuses to relabel one, on purpose:
# two names for one chain id is how an owner reads the wrong network.
tx = eth.EthTransaction(chain_id=11155111, nonce=nonce,
                        max_priority_fee_per_gas=prio, max_fee_per_gas=maxfee,
                        gas_limit=gas, to=TO, value=VALUE)
spend = ops.EthereumSpend(amount_wei=tx.value, destination=tx.to,
                          chain_id=tx.chain_id, chain_name=tx.chain_name(),
                          nonce=tx.nonce, max_fee_wei=tx.max_fee_wei())
print("\n  the device will show:")
for l in spend.render():
    print("     | " + l)

from devkey import device_key
r, s_, y = eth.sign(tx, device_key())
raw = tx.encode_signed(r, s_, y).hex()
recovered = eth.sender(tx, r, s_, y)
print(f"\n  signed on the device")
print(f"     txid      {tx.txid(r, s_, y)}")
print(f"     recovers  {recovered}")
print(f"     matches   {'YES' if recovered.lower() == ADDR.lower() else 'NO -- WRONG KEY'}")
print(f"     raw       {len(raw)//2} bytes")

# The node's own opinion, without broadcasting: estimateGas on the same call.
est = int(rpc("eth_estimateGas", [{"from": ADDR, "to": TO, "value": hex(VALUE)}]), 16)
print(f"\n  node agrees gas is {est} (we send {gas})")
print(f"\n  PRE-FLIGHT {'PASS -- press Send on the bench' if recovered.lower()==ADDR.lower() and bal>=worst and est<=gas else 'FAILED'}")

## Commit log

2026-08-31 CELL-4B: Pi 4B enclosure for z0r0z/cell, generated from Python
    Upstream's shells are hard-coded to a 65x30 Pi Zero bay. This rebuilds the
    same instrument around a Pi 4B, preserving every [OPTICS] constant from
    BUILD.md sections 8 and 9 and regenerating everything marked [DERIVED].
    - cad/partlib.py pure-python CAD kernel (shapely -> watertight shells),
    with an exact angled-bore mesher for the 30/45 deg optics
    - cad/spec.py the dimensional contract, tagged [OPTICS]/[HARDWARE]/[DERIVED]
    - cad/audit.py 125 fit checks; build.py refuses to write STLs if any fail
    - viewer/ three.js viewer, vendored, works offline
    Pi 4B dimensions verified against the official mec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
    [aperture_tube.stl, cartridge.stl, cartridge_null.stl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]
2026-08-31 Verify against the official Pi 4B drawing; fix three real defects
    Read RP-008343-DS-1-raspberry-pi-4-mechanical-drawing.pdf directly (the PDF
    is pure vector with no extractable text, so it was rasterised to 3400 px and
    the dimension chains read off). Three defects found and fixed:
    1. USB stacks are Z=16.0, not the 13.5 I had used (that is Ethernet). Their
    tops reach Z=23.8, ABOVE the old 20 mm part line -- the port window would
    have been cut in half by the shell joint, opening only the bottom of each
    USB port. Part line moved to 26.0.
    2. A Z=5.5 callout I had read as the microSD is actually the top-side DSI and
    CSI FFC connectors. The microSD's under-board protrusion is not dim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
    [shell_lower.stl]
2026-08-31 Measure real component placement and clearance; fix seven more defects
    Bounding boxes cannot see a collision. cad/clearance.py adds exact
    point-to-triangle distance (Ericson 5.1.5) and a penetration-depth test that
    only counts a point when it is inside the other solid AND further than 0.15 mm
    from its surface -- without that tolerance every designed contact reads as a
    collision, because parts that share a face have sampled points on it.
    The distance code was validated against four known answers (15.000, 2.500,
    0.000, 20.000) before being trusted.
    Defects found, all of which would have printed:
    1. Four Ø2.2 spikes on the underside of the case, from Pi standoff pilot
    holes added as SOLI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
    [oled_bezel.stl, optical_head.stl, sensor_carrier.stl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]
2026-08-31 Route and verify the CSI ribbon; add a cutaway view
    "Where is the camera?" exposed a real gap. It sits at r = 14.1 from the read
    spot -- inside the Ø52 head -- so 96% of its vertices are within the head's
    outer radius and it is invisible from every angle. That is forced by the
    optics: upstream fixes the lensless sensor at 20 mm from the spot.
    The consequence was not cosmetic: NOTHING in the design accounted for its
    ribbon. No route, no channel, no check. The camera could not have been
    connected to the Pi.
    CABLE_ROUTE now declares a 9-waypoint centreline with a per-segment
    orientation flag, because an FFC is FLAT (16 x 0.3 mm), not round. That
    distinction is load-bearing: the gap between t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
    [audit.py, build.py, mocks.py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]
2026-08-31 Catch doc drift: ASSEMBLY.md still listed the old bore azimuths
    The azimuths were reallocated when the camera board and laser barrel were
    found overlapping (LEDs to 45/135/225, camera to 0), but ASSEMBLY.md still
    told the builder to put white LED #1 at 0 deg, the IR at 90 and the camera at
    225. Every part would have fitted perfectly and the instrument would have read
    nonsense -- no geometry check can see that, because the geometry is fine.
    check_docs() now asserts ASSEMBLY.md's stated azimuths against spec.py, so the
    human-facing instructions cannot drift from the model again. Also corrected the
    stale "all 108" check count and added PI_SD_H and CAM_PCB_L/W to the
    measure-before-printing tab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
    [audit.py]
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2026-08-31 Add the demo video pipeline: Playwright capture, Kokoro narration, adjustable cut
    Records the real viewer through Playwright's browser-context recordVideo in a
    headless Chromium, so only the viewport is captured and the desktop is never
    touched. One context per scene means one file per scene, so any single scene
    can be re-recorded without disturbing the rest.
    Twelve scenes, one narration line each, generated with Kokoro and paced to the
    measured WAV duration rather than an estimate -- long footage is speed-ramped,
    short footage holds its last frame.
    scenes.json carries a per-scene speed multiplier, applied by setpts for video
    and atempo for audio so pitch stays natural. rerender.py --targe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
2026-08-31 Shrink the head to Ø44: a Ø52 head left the cartridge switch nothing to sense
    The cartridge is only exposed inside the case between the inner front wall and
    the optical head, and that strip is TRAVEL - R - WALL = 31.6 - 26 - 2.4 =
    3.2 mm. At Ø52 there was nowhere to put the cartridge-present microswitch where
    the cartridge could ever press it -- which also meant the laser's hardware
    interlock had nothing to interlock.
    This was a FUNCTIONAL failure that no fit check could see. The switch sat in
    the case with 1.9 mm of clearance on every side and every geometry assertion
    passed; it was simply 19.5 mm from the cartridge and would never be touched. I
    introduced it myself when moving the swit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
    [optical_head.stl, sensor_deck.stl, shell_lower.stl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]
2026-09-02 Implement the touch tier: through-port, flip-mount and touch collar
    Reading upstream's CAD settled how the ring and the cartridge are linked, and
    exposed what is missing underneath it.
    Upstream puts them on ONE axis -- DISH_X and SLOT_X are both 28.5 -- and cuts
    the port as a through-hole, so a finger above and a cartridge below share one
    optical path. But build-sheet.svg labels the head "AS7341 / aperture 3.0 x 6.0
    / 0 degrees observe" facing DOWN at a cartridge 9 mm below, while the finger
    sits on glass ABOVE it. One AS7341 aperture cannot look both ways, and the
    three blood LEDs are aimed downward, so neither the emitters nor the detector
    face the finger. The touch tier is specified in p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
    [sensor_carrier.stl, shell_upper.stl, touch_collar.stl]
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2026-09-02 Add real 3-D assembly animation (replaces the stills cut)
    The previous assembly video was framed stills with callouts over them.
    Nothing moved, so it never actually showed a part going into its hole.
    This drives the real geometry instead:
    cad/gen_assembly_anim.py emits every part as its OWN node (the three
    LEDs are one mesh in the viewer but go into three different bores)
    plus an INSERTION VECTOR per part, computed from spec.py. An LED
    travels down its own 45 deg bore, the laser down 30 deg at azimuth
    270, the camera down 45 deg, the head straight down on +Z, the
    cartridge in from the front on -Y. The motion is the CAD, not a
    guess that looks plausible.
    viewer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
    [gen_assembly_anim.py, record3d.py]
2026-09-02 Fix the head fastening: it was unbuildable, and 4 posts are impossible
    Symptom was "I can't find the AS7341 stuff". Root cause was three separate
    defects in the same place, all of which passed 346 checks.
    * posts az 30 and az 330 sat INSIDE the camera pocket -- distance 0.00, so
    the tap hole opened straight into the camera cavity;
    * all four posts left 0.08 mm of wall to an LED/IR bore, where MIN_WALL is
    1.0. az 30/150/210/330 is exactly 15 deg off the bore azimuths
    45/135/225, which at r=15 is 3.9 mm of arc;
    * in the deck, the AS7341's four M2 holes MERGED with the four post M2.5
    holes -- centres 1.52 mm, radii summing to 2.55 -- into figure-8 slots.
    unary_union m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
    [optical_head.stl, sensor_deck.stl, shell_lower.stl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]
2026-09-02 Record what the new fastening means for the builder
    Moving the screws outside the head changed what has to be BOUGHT: the lug
    column is 33.4 mm of stack, so those three are M2.5 x 35 rather than the
    short screws the old interior posts needed.
    check_screws() recomputes every number in ASSEMBLY.md's fastener table from
    the geometry -- length, what each screw passes through, what it threads into,
    and the engagement -- so a hand-written table cannot go stale the next time a
    thickness moves.
    It also surfaces something worth saying out loud rather than burying: thread
    engagement is 3.8 mm on the lugs (1.5 x diameter) and 2.4 mm on the AS7341
    (1.2 x), both under the usual 2 x rule. The loads are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
    [audit.py]
2026-09-02 Re-cut the assembly video against the corrected head
    The previous cut showed the four-post head and said "four posts at r=15"
    and "346 checks". Narration regenerated and the animation re-recorded off
    the rebuilt GLB, so what is on screen is the geometry that is actually in
    out/stl now.
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2026-09-03 Lettering as second-colour inlays, flush in the recesses
    A recess is absent material, so there was nothing to assign a filament to.
    Each mark now has a matching solid that fills it flush: brand_front_inlay()
    rides the same 0.2 mm ladder as _front_mark_cut and is evaluated at the same
    layer midpoints, so it fills exactly -- no gap for the slicer to bridge, no
    interference for it to resolve; brand_top_inlay() is the plain X-Y extrusion
    the ceiling recess already is.
    Both ride their shell's transform rather than their own. for_print() takes
    companions for this: centred on its own bounds, an inlay lands somewhere else
    entirely, and shell_upper is flipped besides. pack() carries them through its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
    [plate1.3mf, plate2.3mf]
2026-09-03 Space plate parts for brim, not just for geometry
    Bambu reported "conflicts of gcode paths at layer 1" between shell_upper and
    shell_lower. Not a model collision -- the parts were 4 mm apart, which is
    plenty for the meshes, but an auto brim runs about 5 mm a side and theirs
    overlapped. The gap was never a considered value; it was pack()'s default.
    S.PLATE_GAP = 12.0 now, sitting next to PLATE_MAX where the bed limits live,
    and it clears two brims plus margin. Repacked:
    plate 1 246.5 x 195.7 -> 243.5 x 237.3 mm
    plate 2 248.0 x 106.0 -> 248.0 x 177.0 mm
    Both still inside PLATE_MAX, though plate 1 now has only ~6 mm spare in X.
    That is the cost of putting the whole case on one plat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
    [plate1.3mf, plate2.3mf]
2026-09-03 firmware: bench software for the instrument
    Pinout, rails and milestones come from ASSEMBLY.md section 5 and 6; nothing
    here re-derives them. If a pin changes, it changes there first.
    hw.py owns the interlock, and owns it twice. ASSEMBLY.md wires the laser gate
    through the microswitch, so hardware already refuses to fire into an empty
    slot -- but a hardware interlock only fails closed if it was wired right, and
    software should not assume that. Every laser call re-reads GPIO22 and refuses
    on its own account. Emitters initialise off and return to off on exception and
    on interpreter exit: a 650 nm module left on by a crashed script is the exact
    failure the class is shaped around.
    spectro.py d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
    [camera.py, cli.py, display.py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]
2026-09-03 firmware: fix i2cdetect lookup, and stop setup.sh assuming sudo
    Two things the target Pi found that my machine could not.
    selftest.py called i2cdetect bare. Debian keeps it in /usr/sbin, which is not
    on a normal user's PATH, so on a stock Pi OS the very first check died with
    FileNotFoundError and read as "i2c-tools is missing" on a box where it was
    installed and working. Now resolved via shutil.which with the /usr/sbin
    fallback, FileNotFoundError reported as the apt line that fixes it, and
    /dev/i2c-1 checked separately -- a missing bus is a different fault from a
    missing tool and deserves its own message.
    setup.sh assumed passwordless sudo. This Pi has none, so every root step has
    to be re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
    [selftest.py]
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2026-09-03 firmware: 500 ms default integration for a 120 ohm build
    This build has 120 ohm resistors, not the 68/47 the design calls for. With
    ~7 ohm of 2N7000 Rds(on) that is 15.0 mA into each white LED (59% of design)
    and 15.4 mA into the 940 nm (43%), so the whites want 1.7x more integration
    to land in the same place. ATIME 99 / ASTEP 1799 is 500 ms, up from 278.
    Two reasons this is not a compromise worth undoing. Integration is the
    cheapest thing this instrument can spend -- ATIME/ASTEP top out near 47 s and
    the gain sits at 8 with six steps above it, so 1.7x is noise. And LED output
    drifts with junction temperature: at 15 mA they run far cooler than at 28,
    which makes M2's "< 1% RSD over 100 read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
    [spectro.py]
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2026-09-04 firmware: three bugs the real hardware found, and a breadboard stage
    Everything here came from running against the Pi rather than reasoning about
    it.
    gain was being written as a multiplier into a property that wants an ENUM
    INDEX. The default of 8 selected index 8, which is 128x -- so this file
    silently ran at 16x the intended gain from the first commit, and only
    surfaced when 64 went out of range and raised. GAIN_STEPS maps multiplier to
    index and the boundary converts, so callers keep speaking in multipliers.
    check_emitters ran with an empty slot. The emitters aim down at the read
    spot; the AS7341 only ever sees what SCATTERS BACK up the aperture, so with
    nothing in the chamber a perfect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
    [cli.py, display.py, selftest.py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]
2026-09-04 Let the Pi actually be inserted, and check that it can be
    The board could not be got into the shell. Not tight -- impossible. The ports
    stand PI_PORT_PROUD into the wall, so in the fitted position they are already
    inside it, which means the board can only arrive from directly above with the
    port blocks descending inside the wall windows. Those windows started at the
    board plane, leaving solid wall beneath them. Dropping it fouled the ports;
    sliding it clear first needs 3 mm of lateral room against 1.10 mm of cavity.
    The windows now start at the FLOOR.
    check_pi() passed all along because it only ever asked whether the board and
    its port stack HAVE somewhere to be. They did. It never asked wh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
    [plate1.3mf, plate2.3mf, shell_lower.stl]
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2026-09-06 firmware: retire the interlock bypass, and a bench check that measures
    A full component run on the real device, and two things came out of it.
    BENCH_NO_INTERLOCK is gone. It was a stand-in for a slot with no switch in
    it, and its own comment said it existed to be removed. The run showed what
    leaving it costs: the laser fired with nothing seated and the check recorded
    its own interlock as broken. GPIO22 now follows a real switch, so the bypass
    had outlived its reason. Both directions of the contract are asserted --
    refuses when open, enables when seated.
    bench_check.py reports NUMBERS, not verdicts, because where the optical path
    does not exist yet a number says which way it is wrong and a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
    [bench_check.py, hw.py, spectro.py]
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2026-09-06 bridge: be the wallet, do not wrap one
    The extension wrapped window.ethereum, which meant it needed MetaMask present
    to enumerate accounts, read a nonce and broadcast. That is the wrong shape for
    an airgapped signer: there is no hot wallet in the browser to wrap, and the
    thing being wrapped was the part we were trying not to have.
    CELL now announces itself as its own wallet over EIP-6963, and takes
    window.ethereum only when the slot is free -- stamping over a wallet the user
    may still want is not ours to do. It holds an ADDRESS and no key, exactly as a
    watch-only wallet does. Reads and eth_sendRawTransaction go through the
    service worker to a public node; eth_accounts and eth_chainId come f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
    [provision_cell.py]
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2026-09-06 bridge: one frame, because 348 chars did not need two
    A wei.domains commit() framed to 348 base64 chars against a 300 limit, so it
    animated between two QRs for the sake of 48 characters. That limit is
    upstream's, and it is right where upstream uses it: qr.py sizes frames for the
    DEVICE's 240x240 screen showing them to a cheap webcam. This direction is the
    reverse -- a laptop display read by a 720p camera -- and the budget is not the
    same. CHUNK is 700 here.
    The result is v12, 65x65 modules, 5.85 px per module in a 380 px overlay, and
    it round-trips through BarcodeDetector identically. The overlay QR grew from
    280 to 380 px to keep that margin as calldata gets longer.
    Multi-frame is still e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
    [console.py]
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2026-09-07 firmware: the MAX30100 is not a MAX30102, and pretending otherwise fails quietly
    The part on the bench is a MAX30100. The driver was written for a MAX30102.
    They share an address and a family name and almost nothing else, which is the
    dangerous kind of similar: writing 0x03 to what the 30102 calls MODE_CONFIG
    lands on the 30100's FIFO READ POINTER, and neither chip complains.
    MAX30100 MAX30102
    part id 0x11 0x15
    FIFO data 0x05 0x07
    mode config 0x06 0x09
    sample 4 bytes 6 bytes
    resolution 16-bit 18-bit
    channel order IR, RED RED, IR
    The channel order is the one that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
    [pulse.py]
2026-09-07 firmware: a confidence of 1.05 is not a good score, it is a broken one
    The first real finger on the sensor read 42 bpm with confidence 1.05 -- a
    ratio that cannot exceed 1 by construction. 42 bpm is exactly 0.7 Hz, which
    is the band edge, so the peak's neighbourhood reached below the band while
    the denominator did not: the numerator counted energy the denominator never
    saw.
    It flattered exactly the readings nearest the boundary, which are the ones
    least deserving of it -- a 42 bpm lock is far more likely to be residual
    motion or breathing than a real resting rate. Both ends of the window are now
    clamped into the band, and the same band-edge signal scores 0.999.
    The synthetic suite never ca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
    [pulse.py]
2026-09-08 the instrument, the console, and what the bench actually taught
    The repo documented the CAD and nothing else; the firmware that runs the
    gates, the bridge that feeds it transactions, and the console you watch it
    on were all untracked or undescribed.
    Adds gate_console.py -- the live readout on the Pi's own screen -- and
    firmware/diag/, one script per question, because the failures on this
    instrument are not distinguishable from the outside: a blocked aperture, a
    dead emitter, a disabled ADC and an empty chamber all read as zero, and zero
    is the value the blood gate has to trust absolutely.
    Firmware fixes carried in with it:
    spectro.wake() forces PON|SP_EN on construction. After a brownou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
    [head_chair.stl, optical_head.stl, plate1.3mf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]
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2026-09-08 console: the airgap, as one path -- camera, gate, signature, QR back
    Two halves existed and neither was a wallet. The T key built its own Sepolia
    transaction to a fixed address, so it could gate a signature but could not
    sign what a browser handed it. qrsign.py rebuilt a transaction from a frame,
    but read that frame from a FILE and signed behind no gate at all.
    X now runs the whole loop: read the frames off the USB camera, reassemble the
    pNofM payload, rebuild the transaction FROM ITS FIELDS, show the owner what
    it commits to, take a FRESH pulse, and only then sign -- rendering the signed
    transaction back as a QR for the browser to read.
    Two things it refuses to get wrong:
    The pulse is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
    [gate_console.py]
2026-09-08 console: a signature no finger can authorise
    The pulse path proves a person is present. It cannot prove a person bled,
    and until now nothing in this device could -- X read a pulse and signed, so
    with blood in the well and every chemistry gate green, the signature was
    still authorised by a fingertip. The instrument measured six gates and then
    asked a seventh question that had nothing to do with them.
    B runs the gates and makes the answer load-bearing. Every one must return
    passed; a single failure signs nothing and says which gate refused.
    The order is forced by the physics rather than convenience. Chemistry first:
    it is fast, and it is what separates haem from red dye -- ketchup clears the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
    [gate_console.py]
2026-09-08 console: put it on the device's own screen, not just the desktop
    The console rendered everything to a monitor and never wrote a byte to the
    OLED, which was sitting on the bus at 0x3c the whole time. For a demo that
    is a cosmetic gap; for this device it is the wrong claim. The airgap rests
    on the owner reading what they are about to sign on hardware that has no
    network -- a desktop has one, so a transaction only ever shown there proves
    nothing about the gap it is supposed to cross.
    The blood path now narrates itself on the panel: dark, white patch, advance
    to stop 2, which gate refused and by how much, the clot watch, and -- before
    any key is fetched -- the rendered transaction itself, paged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
    [gate_console.py]
2026-09-09 firmware: the resistor the build actually has, and the timing that follows
    hw.py's header said 120 ohm on all three emitters. spectro.EMITTER_OHMS said
    220. Both cannot be true, and the disagreement is not cosmetic: atime_for()
    scales integration time from EMITTER_OHMS specifically to hold collected
    light constant as the resistor changes, so the constant IS the calibration.
    A day of bench scripts copied atime=99 -- the 120 ohm timing -- out of the
    console. Every reading taken today collected 1.8x less light than the
    hardware could deliver, and it presented as a dim instrument rather than as
    a wrong number, which is the worst way for a calibration constant to fail.
    The scripts now derive it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
    [chem2.py, findwell.py, floattest.py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]
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2026-09-09 console: survive white #2 being gone
    WHITE2_IS_VIOLET makes Bench.white_2 None -- exactly one device owns that
    pin, and the bore holds one LED. The console did not get the message: three
    places drove the pair directly, so the preview lamp raised on every tick and
    the live colour read raised on every attempt.
    The failure mode is worse than the exception. A preview lamp that dies leaves
    a black camera pane, which is indistinguishable from a dark chamber, and the
    spectrometer panel showed a traceback where a colour belongs. Both look like
    optics problems and neither is.
    [gate_console.py]
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2026-09-09 console: show the signature as both a QR and the bytes, and let the log scroll
    Two things the signing path got wrong at the moment it mattered most.
    The signed screen drew the QR at a fixed scale, so on a 1520x651 display it
    overflowed its own window and became unscannable -- the one artefact the
    whole device exists to produce, rendered too large to read. It is now sized
    from the screen height, and it shows the raw hex beside it. Both forms
    deliberately: the QR is how the signature crosses the gap, the hex is what
    can be read, checked and pasted when a camera will not cooperate. They are
    the same 144 bytes.
    The SIGN panel was a Label truncated to 16 lines. A gate report plus a
    rendered tra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
    [gate_console.py]
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
